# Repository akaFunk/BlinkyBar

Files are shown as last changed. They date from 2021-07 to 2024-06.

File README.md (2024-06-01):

# BlinkyBar
The BlinkyBar is a modular LED light painting device based on the WS2812B programmable RGB LEDs. It features modules with a length of approximately 250mm, which can be attached to a host module of an arbitrary length. The host module holds a Raspberry Pi Zero W, which provides access to the device with a Wifi access point. A website running on the Raspi allows to upload an image. Once the trigger button on the host module is pressed, the image is played back one column after another. Combining this with a long time expose will paint the uploaded image into thin air.

We are currently working on the first release. Images made with an earlier version are shown below. This older version featured only 60 LEDs per meter, while the new one will have 180 LEDs per meter.

## Images
Examples of the old version:
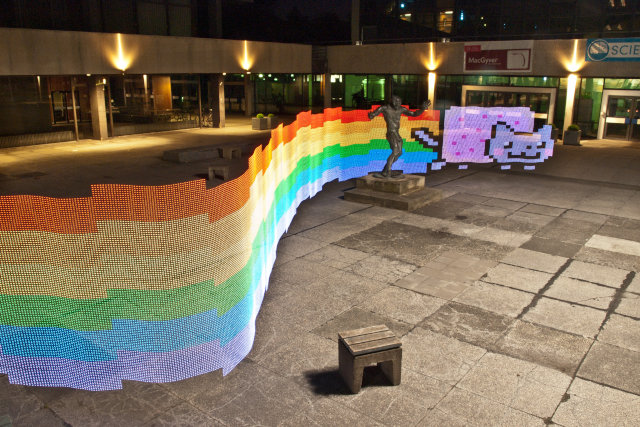
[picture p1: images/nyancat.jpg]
Example Image 1

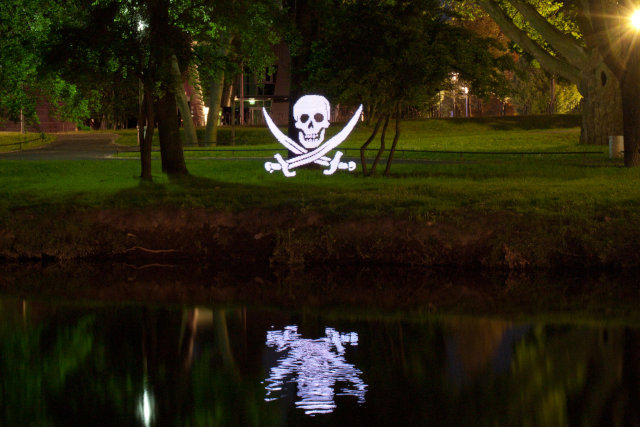
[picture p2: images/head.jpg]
Example Image 2


3D rendering of the current main module:
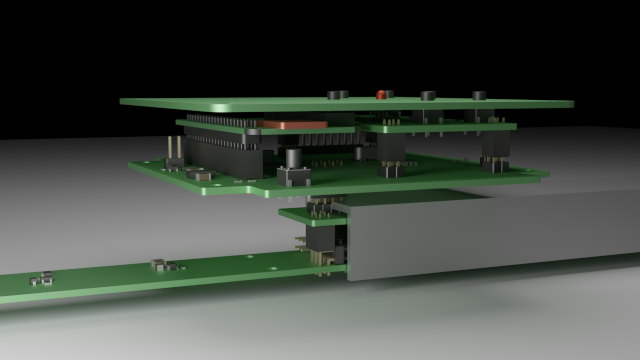
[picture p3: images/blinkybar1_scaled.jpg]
Example Image 1

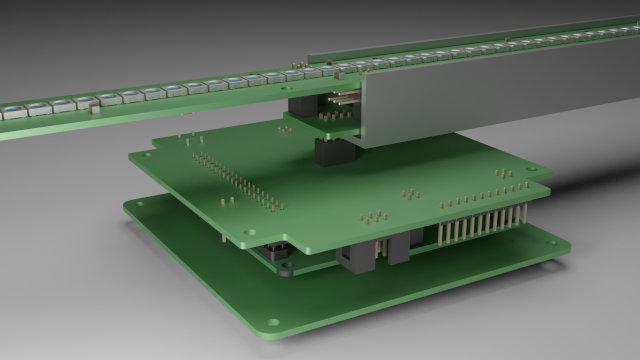
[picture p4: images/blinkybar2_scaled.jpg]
Example Image 1


Images of the first prototype:
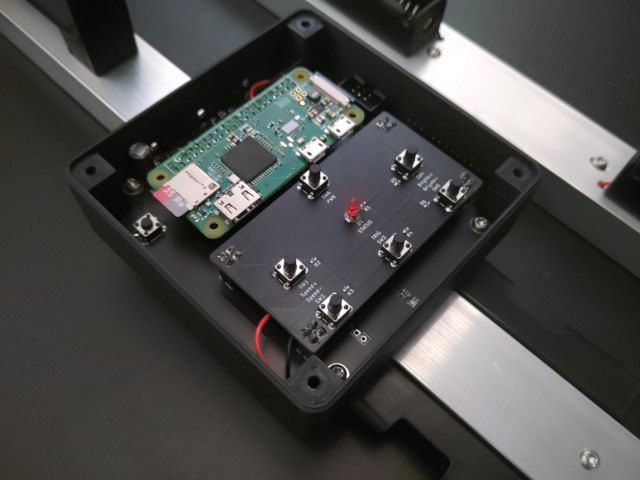
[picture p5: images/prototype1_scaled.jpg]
Example Image 1

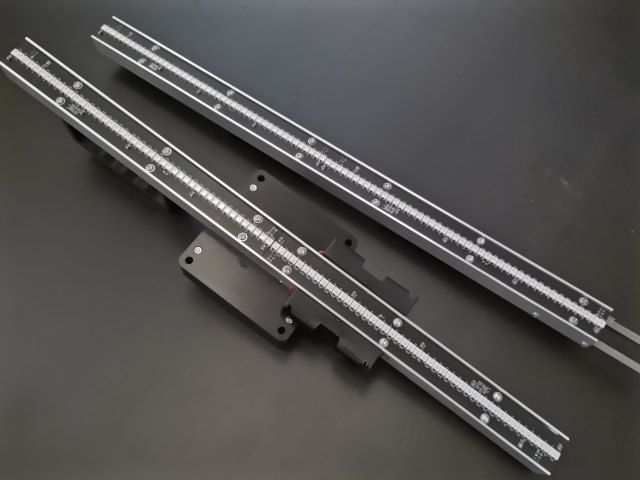
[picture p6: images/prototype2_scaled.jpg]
Example Image 1

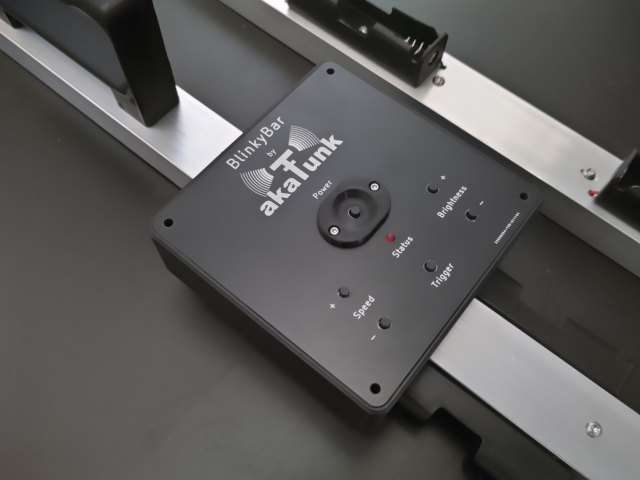
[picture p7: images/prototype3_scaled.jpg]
Example Image 1

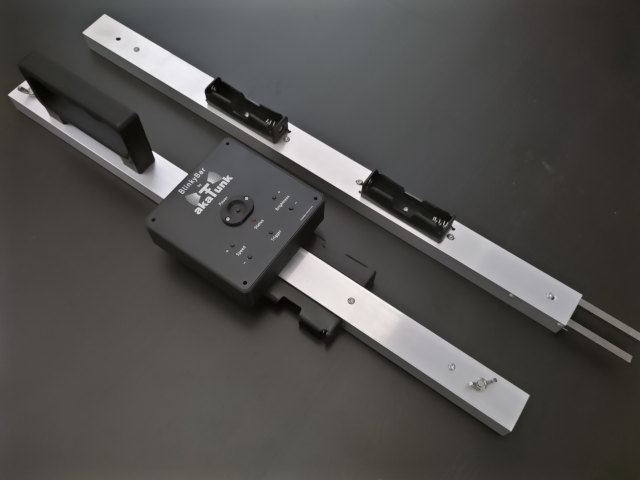
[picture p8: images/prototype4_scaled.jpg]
Example Image 1


## Building BlinkyBar

### Issues to be aware of
BlinkyBar is still in development and there are currently a few issues, which are important to note if you want to build it. They will be addressed in the future:
- The 1117 LDO is not working with the currently populated MLCC output capacitors. Their ESR is too low. You will hear an annoying high pitch tone and have a ~400 mVpp triangle on the output voltage. Either replace the output capacitors with Aluminium Electrolytic types, solder a 0.5 Ohm resistor in series with the capacitors, or use a different LDO (for example BL8071CLBTR33 or AP2114H-3.3TRG1). Currently we have tested only using the Aluminium Electrolytic caps which works fine.
- The modules are not able to power down automatically if the host module powers down. Please make sure to remove the batteries, otherwise they will be empty after some time. However, the battery under-voltage protection should work for both the host and the modules, so your batteries are safe.

### Parts
Additional part required for a BlinkyBar with 4 modules and the main unit, i.e., 10 module PCBs and a length of 2475 mm and 450 LEDs.
For the PCBs you will find lists in CSV format exported from KiCad in each of the PCBs output folder.

| Description | Count | 3D Model |
|---|---|---|
| U-Profile, 30x20x2x495 mm (WxHxTxL), Aluminum | 1 | main_profile |
| U-Profile, 30x20x2x495 mm (WxHxTxL), Aluminum | 4 | module_profile |
| 6x6x100 mm, Steel | 8 | module_bolt |
| 3D-printed stand for the module PCB | 15 | module_stand |
| 3D-printed power button protector | 1 | main_button_protector |
| 3D-printed main case | 1 | main_case |
| 3D-printed handle | 1 | main_handle |
| 18650 Holder | 12 | 18650_holder |
| Plate, 35x25x3 mm, Steel | 4 | module_plate |
| Main PCB holding the Raspberry Pi Zero and the user interface PCB | 1 | main_pcb |
| Main PCB adapter to combine and raise the two connector fro the module pcb within the main module | 1 | main_pcb_adapter |
| Main PCB front panel as the case cover | 1 | main_pcb_front |
| Main PCB user interface holding a few buttons and an LED | 1 | main_pcb_ui |
| Module PCB with the LEDs | 10 | module_pcb |
| M4x12 wing screw (DIN 316) | 4 | |
| M3x5 flat head screw (ISO7380) to hold the case to the profile | 2 | |
| M3x4 countersunk head screw (ISO 14581) to hold the battery holders | 24 | |
| M3 nut (ISO 4032) to hold the battery holders in the main case | 4 | |
| M3x8 flat head screw (ISO7380) to hold the main PCB in the case | 4 | |
| M3 nut (ISO 4032) to hold the main PCB in the case | 4 | |
| M3x20 flat head screw (ISO7380) to hold the front panel PCB to the case | 4 | |
| M3 nut (ISO 4032) to hold the front panel PCB to the case | 4 | |
| M3x12 flat head screw (ISO7380) to hold the stand to the profile | 28 | |
| M3x20 flat head screw (ISO7380) to hold the handle and two of the stands to the profile | 2 | |
| M3 nut (ISO 4032) to hold the stand to the profile | 30 | |
| M3x8 flat head screw (ISO7380) to hold the module PCB to the stand | 60 | |
| M3 nut (ISO 4032) to hold the module PCB to the stand | 60 | |
| M2x5 flat head screw (ISO7380) to hold the power button protector to the front panel PCB | 2 | |
| M2 nut (ISO 4032) to hold the power button protector to the front panel PCB | 2 | |
| M3x8 flat head screw (ISO7380) to hold the steel bolts to the profile | 16 | |

### Replacement parts
Some MPN in the CSV/schematics are just some random ones, for example for pin headers, which fit and were available at the time of design. Those may be replaced with similar types. A (bar far not complete) list of such parts is given below:

| Part | Description |Replacements |
|---|---|---|

# TODO/Further development
- Make everything much simpler, especially the bus topology, mechanical design, and power design
- Use smaller LEDs, for example SK6805-EC15, and increase LED density

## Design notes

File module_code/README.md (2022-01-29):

# Module Microcontroller Code
This folder contains the code for the microcontroller located on each module. This micro will receive the image data which will be used for the module's LEDs, save it into the flash memory and play it back once triggered.

The used microcontroller is an ATmega328p, which is the same as the one on the Arduino Uno. But we do not support the Arduino bootloader or using the Arduino IDE. This is a larger project and for that one should use proper tools.

## Building & Flashing
You need the avr-gcc and avr-binutils packages for building. Flashing requires avrdude and an external ISP prommer like the AVR ISP mkII, Atmel ICE, or similar.

To build the sources (there is also a pre-compiled hex file) type
```sh
$ make
```

After that you should modify the Makefile to fit your prommer. By default an Atmel ICE is expected, connected to the ISP header. See
```sh
$ avrdude -c help
```
for a list of supported prommers. After doing that flash each module with:
```sh
$ make flash
```
You may also want to burn the fuses:
```sh
$ make fuses
```
If you get some error message telling you that he was not able to access your prommer, your user probably doesn't have the right permission to access it. Use your favorite internet search engine to solve this problem, the keywords you are looking for are the name of your prommer, avrdude and udev (you need to add udev rules for it). If you are lazy, just run the install command with root privilegs.

## Bus System and Packets
A small recap of the hardware structure, for a detailed explanation of the hardware take a look at the folder ../Module_PCB.

The modules are daisy-chained through their UART. The TX of the host goes to the RX of the first module, the first module's TX goes to the second module's RX and so on. This is the downstream path.

There is also an upstream path. Each module can (software-controlled) bridge it's TX to the return path. The last module is the one which actually has to do this to get a closed daisy-chain.

Besides the daisy-chain there is the additional TRIGI/TRIGO signal. This signal comes from the microcontroller on the host. A rising edge on this signal signals the trigger for the output of the next column of the image.

The daisy-chained connection is used to transmit packets between the host and the modules. The packet's header contains information about the source and destination address, the type of the packet (i.e., a command), as well as the length of the data, and a few other things. The data follows the header and may have a length of up to 256 bytes and may also be of zero length.

If a packet's desination address is either the broadcast address or does not match the modules address, it is forwarded to the next module.

The big question is: How does a module determine its address? We decided against a hardware coding, as the modules would not be as modular - obviously. The host first sends a message to the broadcast address, telling every module to disable its uplink path and just transmit the packets to the next modules. In this configuration the host will not get any packets form the last module, as it will only forward them to the next module, which does not exist. This "return reset" message also causes all modules to set their address to 0. Next, the host will transmit a command to this address, containing a new unique address. The first module receives this message, sets its new address, enables the return path, acknowledges the reception, and disables the return path. This process is repeated until the host does not receive any answer. The last module that did answer will then get an extra message, telling it to enable its return path.

Here is the structure of the packet:
```c
typedef struct
{
    uint8_t magic;
    uint8_t type;
    uint8_t src;
    uint8_t dst;
    uint16_t len;
    uint8_t data[MESSAGE_MAX_DATA_SIZE];
} message_t;

```
with the following parameters:
- **magic** is a magic byte of value 0xab, which is always the first byte of a message. It is used to identify the start of a message in case of a loss of synchronization. Eventually a module will re-synchronize after a few packets.
- **type** is the type or command of the message, see below.
- **src** is the the source address. The host is 0xfe and 0xff is the broadcast address.
- **dst** is the destination address.
- **len** is the length of the data field as little endian.
- **data** is the data, which may have any length between 0 and 256.

The following message types are known:
- **MESSAGE_TYPE_RET_RST**: Reset the modules address, disable return path (RETO, ~RET_EN), always a broadcast message, len=0
- **MESSAGE_TYPE_ADDR**: New address for the module, len=1 (new address). The module will set the new address, enable the return path, send an ack message, and disable return path.
- **MESSAGE_TYPE_RET_SET**: Enable the module's return path (RETO, ~RET_EN), len=0.
- **MESSAGE_TYPE_PING**: Ping message, response with an ACK.
- **MESSAGE_TYPE_STAT**: Display a status value with the LEDs, len=1 (status vlaue).
- **MESSAGE_TYPE_DEL**: Delete the module's flash, len=0. ACK is returned when flash is deleted. Note that the module will not forward other messages while deleting the flash. It is therefore advised to send this message either as a broadcast or to the last module in the chain at first.
- **MESSAGE_TYPE_DATA**: Next data block for the module, len=1..256. The flash block size is 256 bytes and one column has 135 bytes per module.
- **MESSAGE_TYPE_PREP**: All data transmitted to modules, signal for the modules to prepare for trigger, len=0. The module will load the first set of data into the RAM.
- **MESSAGE_TYPE_TRIG**: Trigger a column - just for debug purposes, normal operation is though TRIGI signal interrupt.
- **MESSAGE_TYPE_DONE**: Playback is done, normal operation can continue.
- **MESSAGE_TYPE_ACK**: ACK last message (also used as pong), len=0.
- **MESSAGE_TYPE_NACK**: NACK last message, len=0.

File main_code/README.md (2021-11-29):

# Main PCB AVR code
This folder contains the code for the AVR on the main PCB. The purpose of this controller is battery monitoring, power management, and generation of the trigger signal for the modules.

Once the controller turns on by pushing the button connected to the `MASTER_ON` signal, it is responsible to set `PWR_EN` high to keep the power supply turned on. If the battery voltage is too low, the AVR will turn off the power supply by driving the `PWR_EN` line low. This will also turn off the power of the AVR itself. Before that it will notify the Pi, so the Pi can shut down the modules as they will not be needed if the main module has no power.

The AVR talks to the Raspberry Pi using an SPI. On the Pi side the SPI1 is used in master mode, which needs to be activated using an additional overlay. See the readme file in `buildroot_external` folder for details on that. The AVR uses its only internal hardware SPI, which is shared with the `ISP` interface for promming the AVR. The two 330 Ohm resistors `R7` and `R8` make sure that there are no collisions while debugging and the `ISP` interface is the primary one. The AVR runs at 8 MHz. 16 MHz is not possible, as the supply voltage is only 3.3V.

The Pi will set the period and on time of the trigger signal, how many colums there are and it will start/stop the trigger signal.

## SPI protocoll
The SPI clock should be fairly low, to make sure that the AVR can keep up. Don't know the exact value, 10 kHz works.

The protocoll is a single packet of 5 bytes in both directions. These 5 bytes have to be encapsulated in a single chip-select sequence. The packet from the Pi to the AVR contains the following data, all values are little endian:

| Bytes | Meaning |
|---|---|
| 1 | Command flags: <br> bit 0: start trigger<br>bit 1: stop trigger <br> bit 2: infinite repeat <br> If nothing is set, the Pi only wants to read the voltage/timer_counter and no action is carried out and the local state is not altered. |
| 2 | Period of the trigger signal, given in µs |
| 2 | On-time of the trigger signal, given in µs |
| 2 | Trigger count, number of negative pulses on the trigger line |

And the answer, which is returned in each request contains the following information:

| Bytes | Meaning |
|---|---|
| 1 | Magic byte, always 0x31 |
| 2 | Battery voltage, given in mV |
| 2 | Current timer counter value of the current progress, which counts from 0 to the period value minus 1 |
| 1 | Shutdown request, 1 if the power button was pressed or the battery voltage is too low, otherwise 0 |
| 1 | Magic byte, always 0x41 |

TODO: Add a automatic shutdown if we have not heard from the Pi in a while. This would also be helpfull for the modules.

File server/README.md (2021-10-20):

# BlinkyBar Server

The server is small Python script running on the main module's Raspberry PI Zero W. The Pi provides a Wifi access point. Once connected, the server is reachable under http://192.168.138.1. The server provides the necesarry website and API to control the BlinkyBar. This includes uploading images, setting the speed, brightness, trigger delay, and a few other things. It also allows to trigger the BlinkyBar, additionally to the hardware button on the BlinkyBar itself.

## API

The server is written in Python 3 and based on [cherrypy](cherrypy.org), which provides a simple webserver and integrates easily into python. There are three different endpoints for the API:

### settings

Settings can take several parameters:

-   **speed** is a floating point value between 0.1 and 10, given in meters per second. It defines the column playback speed of the image. The default value is 2.0.
-   **brightness** is the brightness of the image as a floating point value between 0 and 1. Settings this value will trigger an upload of the image to the modules. The default value is 1.
-   **color_temperature** is the temperature of the surrounding light sources. The image is converted to reflect this color temperature. The default value, which makes (almost) no changes to the image is 6500 K. The valid range is between 1000 and 10000 K.
-   **trigger_delay** sets the delay between pressing the trigger button and starting the playback of the image. The value is given in seconds and any positive floating points value is allowed. The default value is 0.
-   **mirror** mirrors the image. A change will trigger an image upload.
-   **allow_scaling** defines if the BlinkyBar is allowed to scale the image or not. This allows to prepare pixel-precise images. Note that if the image height is exactly the same as the number of available pixels, the BlinkyBar will not scale the image as well. If scaling is not allowed and the image is smaller than the current BlinkyBar configuration, only the upper pixels will be used. If no scaling is allowed and the image is larger, the image will be cut at the bottom. Accepted values are true or false. A change of this value might trigger an image upload, if the result will be different. The default value is true.
-   **repeat** defines, if the image shall be repeated endlessly.
-   **pixel_mode** defines, if the playback should display pixels instead of hoizontal lines. If turned on, the modules will turn the LEDs on and off for each column with a durty cycle of 50 %, creating pixels in stead of horzontal lines.

All parameters are optional. A query looks, for example, like this:

http://192.168.138.1/settings?speed=1.0&allow_scaling=true

All queries will return a JSON string with the following structure:

```json
{
    "success": true,
    "error_msg": "",
    "brightness": 0.5,
    "speed": 0.5,
    "color_temperature": 6000,
    "trigger_delay": 1.0,
    "mirror": false,
    "allow_scaling": true,
    "repeat": false,
    "pixel_mode": true,
    "image_hash": "01ba4719c80b6fe911b091a7c05124b64eeece964e09c058ef8f9805daca546b",
    "progress_status": "noimage",
    "prograss_value": 0.0,
    "progress_msg": "",
    "system_error_msg": ""
}
```

If the "success" variable is false it indicates an error in the query. In that case the "error_msg" holds an error message.

Additionally the structure holds a few variables, indicating the state of the system:

-   **image_hash** contains the hash of the current scaled image, which can be used by the frontend to figure out if the image has changed since the last request. If that is the case, the frontend can ask for the new image.

-   **progress_status** may be any of "noimage", "processing", "ready", or "playing". "noimage" means that no image is available to be triggered, "processing" means that an uploaded image is currently being processed, "ready" means that the uploaded image is ready to be triggered, and "playing" means that the image is currently beeing played back. In the last case, a trigger will stop the playback.

-   **prograss_value** is a float value between 0 and 1. It can be used to display a loading bar while the an image is beeing processed or played. It is only valid if "progress_status" is either "processing" or "playing".

-   **progress_msg** contains a more detailed message about what is currently happening, especially during the image processing. It is only valid if "progress_status" is either "processing" or "playing".

-   **system_error_msg** may contain a system critical error message. If this string is not empty, the BlinkyBar will not function as expected and the message should be shown to the user.

### set_image

Upload an image to the BlinkyBar. The image has to be attached in the POST as a multipart/form-data object in the variable image_obj. A new image will trigger an image upload to the modules.

The endpoint is: http://192.168.138.1/set_image + POST data

### get_image

Returns the currently stored image. The server internally converts the image to a PNG file on upload and this is what you will get here.

Here is an example: http://192.168.138.1/get_image

### get_image_scaled

Returns the scaled version of the image, which is currently used for the LEDs. The image is of type PNG.

Here is an example: http://192.168.138.1/get_image_scaled

### Trigger

Triggers the image playback. If the playback is already running, it stops it. Can only be called if "progress_status" is "ready" or "playing".

## Website

The website is delivered by the server to the webbrowser and provides the GUI for the BlinkyBar. The application is based on [Vue.js](https://vuejs.org/), version 3.

TODO: A detailed description to follow, once implemented ;)

TODO: Screenshots

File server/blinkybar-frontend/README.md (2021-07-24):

# ledleiste-frontend

## Project setup
```
npm install
```

### Compiles and hot-reloads for development
```
npm run serve
```

### Compiles and minifies for production
```
npm run build
```

### Lints and fixes files
```
npm run lint
```

### Customize configuration
See [Configuration Reference](https://cli.vuejs.org/config/).

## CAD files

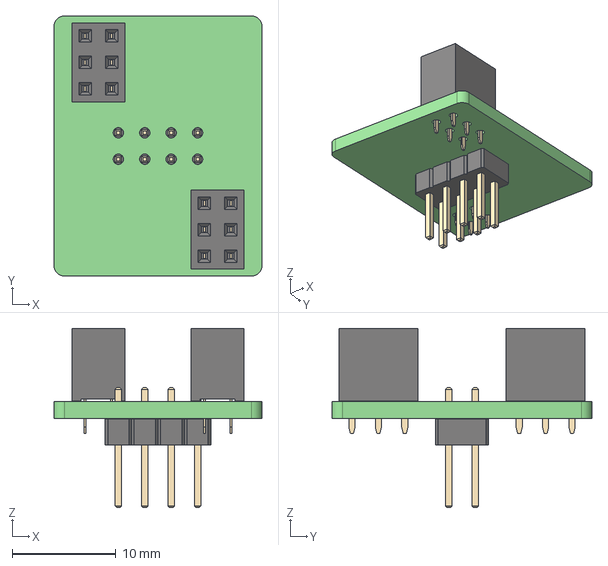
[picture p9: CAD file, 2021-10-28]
main_pcb_adapter/main_pcb_adapter.step
20.0 x 25.0 x 17.2 mm

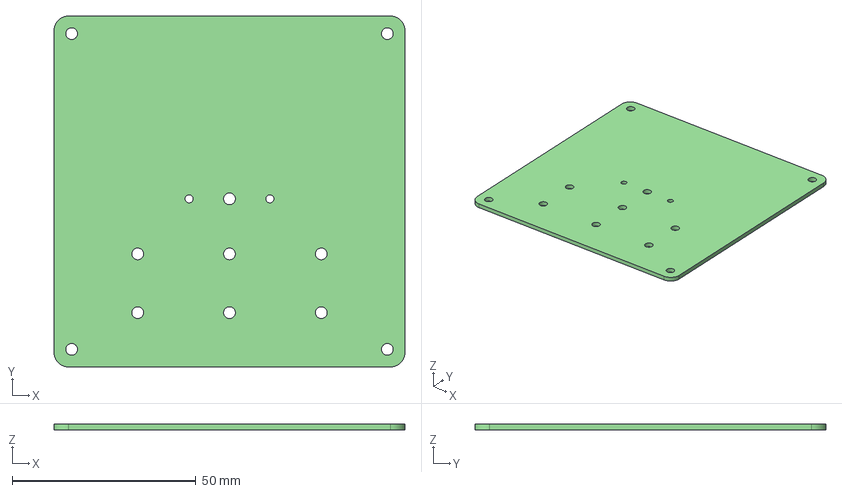
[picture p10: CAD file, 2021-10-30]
main_pcb_front/main_pcb_front.step
95.6 x 95.6 x 1.60 mm

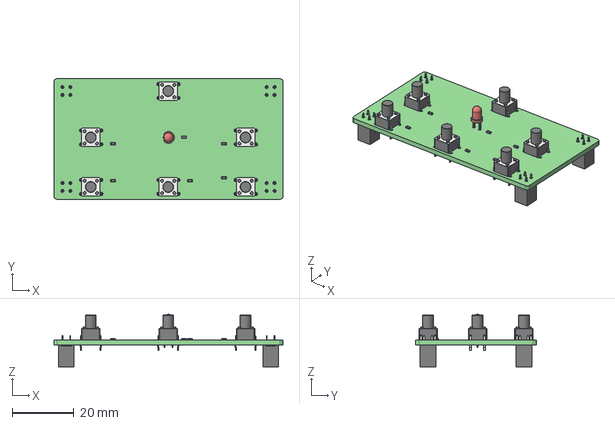
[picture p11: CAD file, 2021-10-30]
main_pcb_ui/output/main_pcb_ui.step
74.0 x 39.0 x 17.0 mm

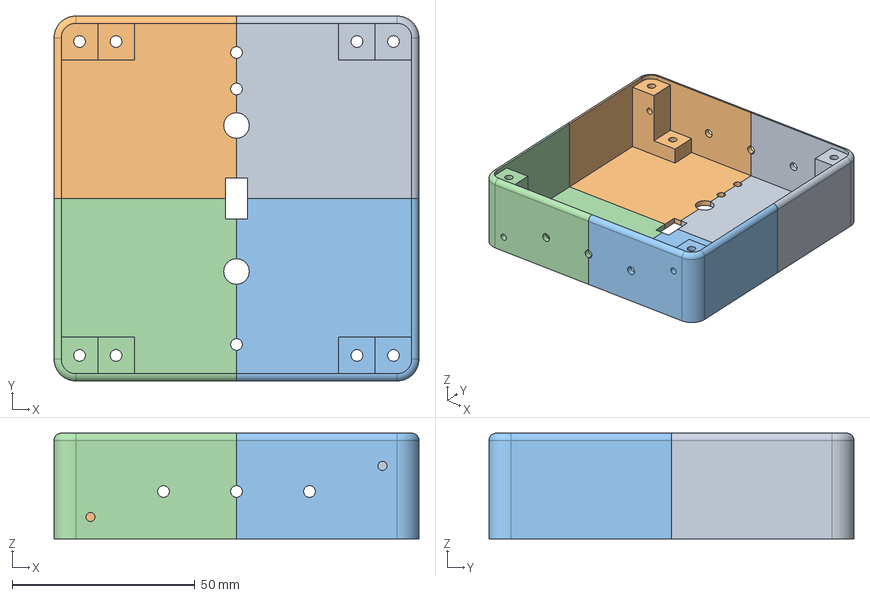
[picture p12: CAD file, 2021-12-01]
mechanics/main_case.step
100.0 x 100.0 x 29.0 mm

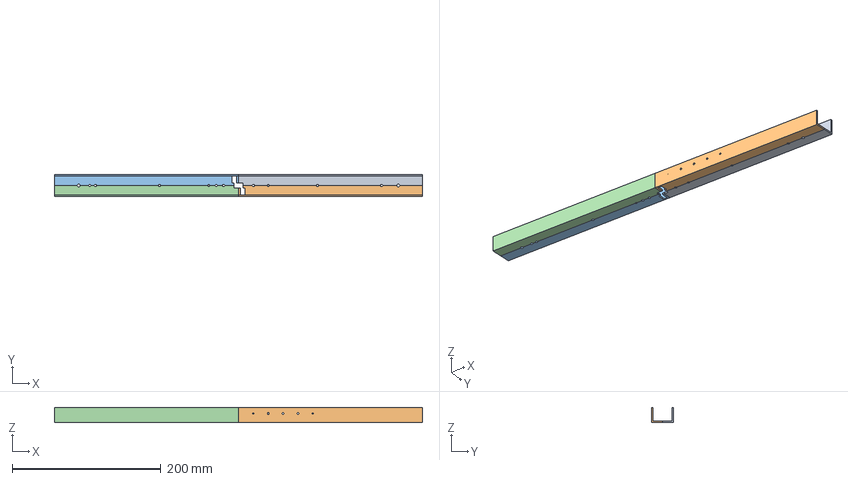
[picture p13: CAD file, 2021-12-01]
mechanics/main_profile.step
495.0 x 30.0 x 20.0 mm

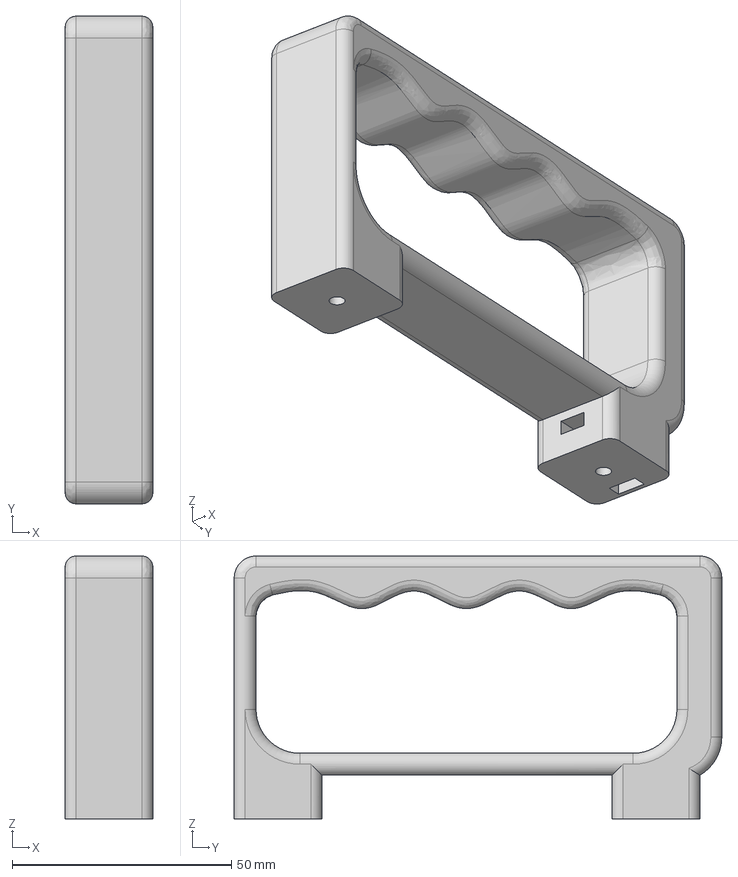
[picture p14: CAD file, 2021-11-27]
mechanics/main_handle.step
20.0 x 111.2 x 60.0 mm

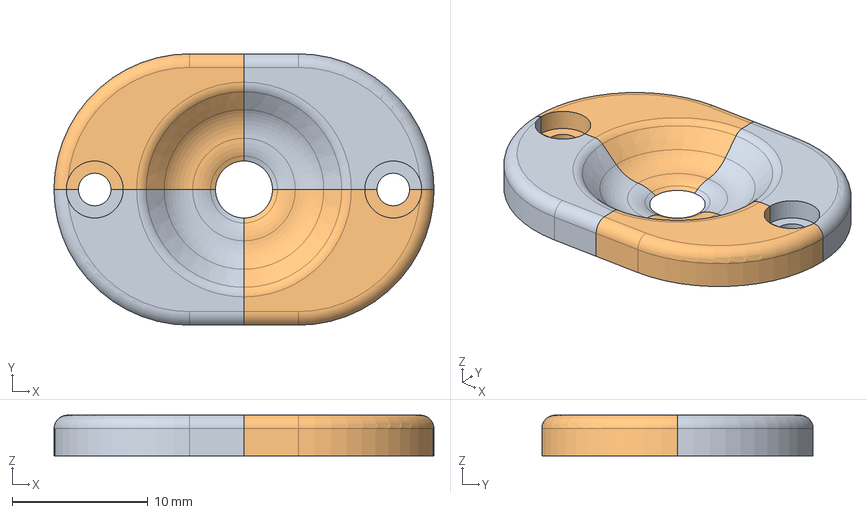
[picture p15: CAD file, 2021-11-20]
mechanics/main_button_protector.step
28.0 x 20.0 x 3.00 mm

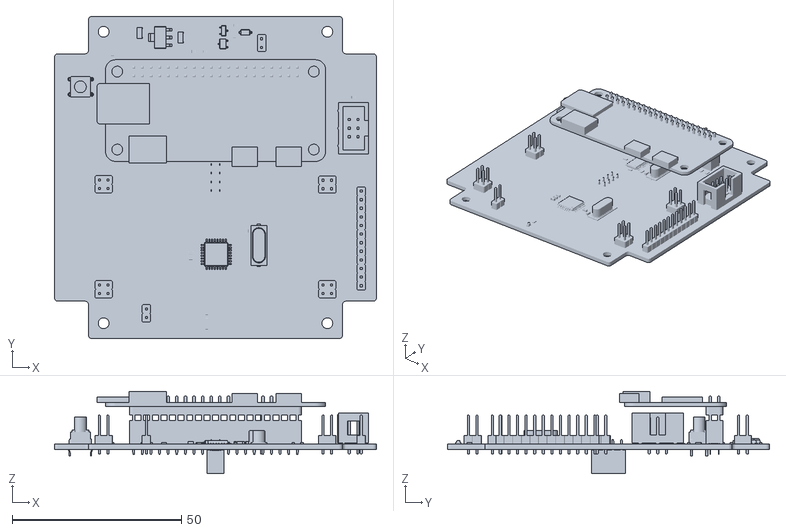
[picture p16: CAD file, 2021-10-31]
mechanics/main_pcb.stl
95.0 x 95.0 x 24.2

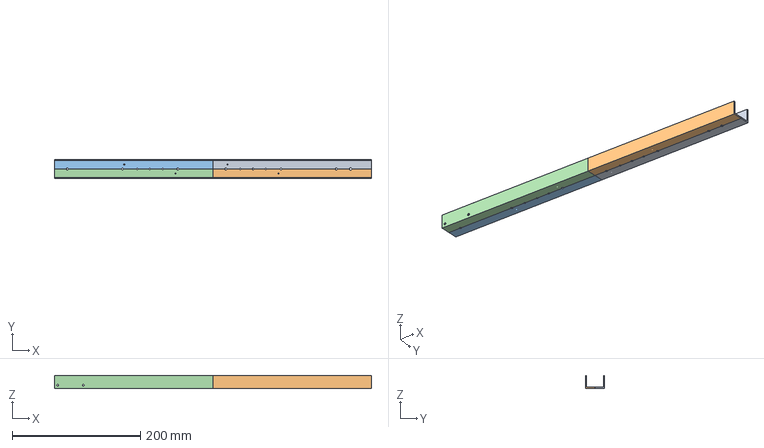
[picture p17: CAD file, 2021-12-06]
mechanics/module_profile.step
495.0 x 30.0 x 20.0 mm

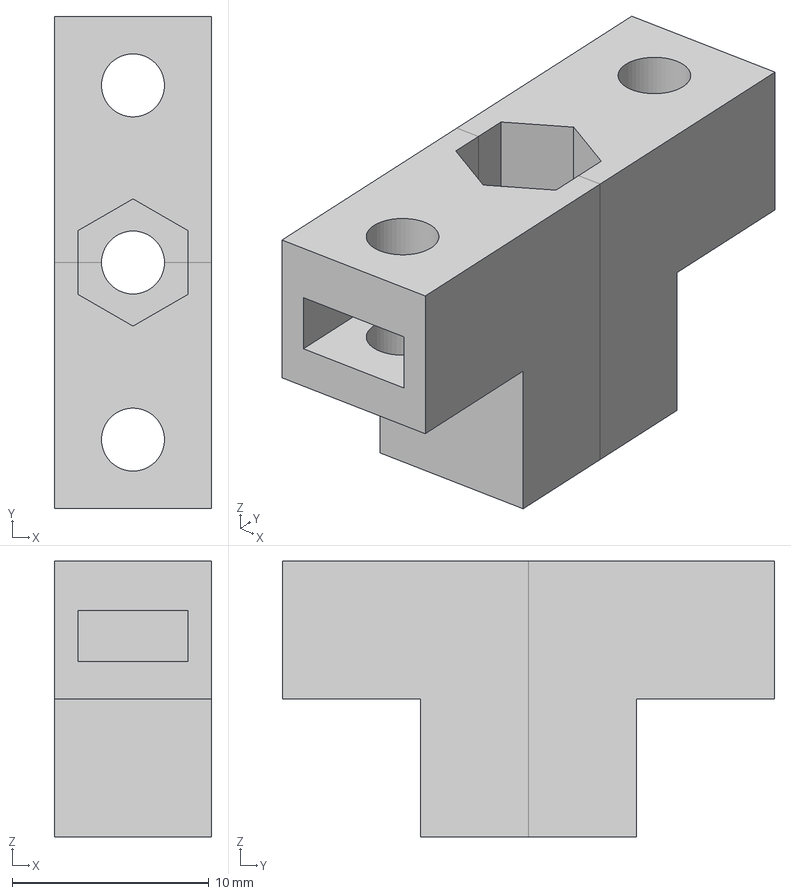
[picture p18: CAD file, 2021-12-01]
mechanics/module_stand.step
8.00 x 25.0 x 14.0 mm

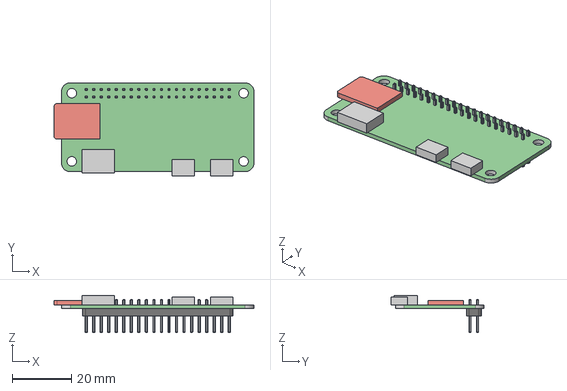
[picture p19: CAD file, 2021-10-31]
mechanics/PiZero.step
67.5 x 31.5 x 12.6 mm

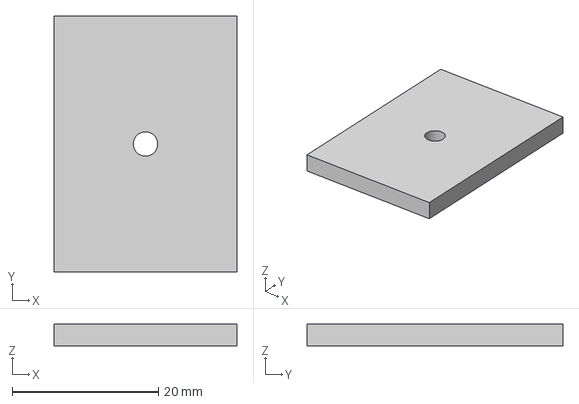
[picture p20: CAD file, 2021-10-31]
mechanics/module_plate.step
25.0 x 35.0 x 3.00 mm

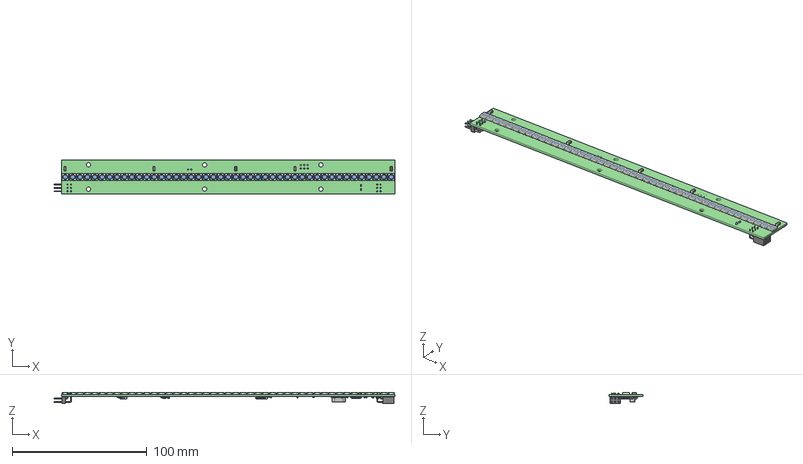
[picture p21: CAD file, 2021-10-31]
mechanics/module_pcb.step
253.1 x 25.0 x 8.38 mm

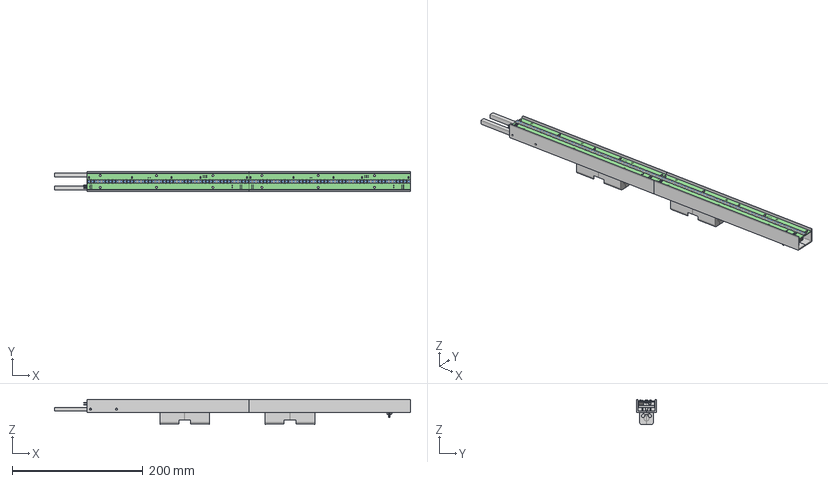
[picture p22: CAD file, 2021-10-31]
mechanics/module.step
545.0 x 30.0 x 38.5 mm
module_stand x 6
module_profile
module_bolt x 2
92595A200_Iron Wing-Head Thumb Screw
module_plate
18620_holder x 2

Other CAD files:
main_pcb_adapter/output/main_pcb_adapter.step
mechanics/main_pcb_ui.step
mechanics/main_pcb_adapter.step
mechanics/main_pcb_front.step
mechanics/18620_holder v3.f3d
mechanics/18620_holder v3.step
mechanics/18620_holder v3.stl
mechanics/PiZero.f3d
mechanics/PiZero.stl
mechanics/main.f3z
mechanics/main_button_protector.f3d
mechanics/main_button_protector.stl
mechanics/main_case.f3d
mechanics/main_case.stl
mechanics/main_handle.f3d
mechanics/main_handle.stl
mechanics/main_pcb.f3d
mechanics/main_pcb_adapter.f3d
mechanics/main_pcb_adapter.stl
mechanics/main_pcb_front.f3d
mechanics/main_pcb_front.stl
mechanics/main_pcb_ui.f3d
mechanics/main_pcb_ui.stl
mechanics/main_profile.f3d
mechanics/main_profile.stl
mechanics/module.f3z
mechanics/module_bolt.f3d
mechanics/module_bolt.step
mechanics/module_bolt.stl
mechanics/module_pcb.f3d
mechanics/module_plate.f3d
mechanics/module_plate.stl
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

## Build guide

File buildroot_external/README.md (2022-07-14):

# Buildroot config
You need a Linux on the Raspberry Pi Zero with some custom configuration (including device-tree stuff). This folder includes the files required to make a custom buildroot build. This custom embedded Linux has a few advantages:
- The image only includes what is really needed. This will decrease the size of the image substantially (currently we need less than 100 MB) and it also improves the boot time (currently we need ~5 seconds).
- The image contains multiple partitions. The boot and system partition are mounted read only (including noatime). The data partition contains the current configuration. It is mounted rw only when required. This reduces wear of the SD card and the risk of a damaged it when the Pi is turned off without a proper shutdown.
- We need a custom device tree to enable the SPI to UART converter, which can be easily integrated into the buildroot system.
Nevertheless, it is possible to use the standard RaspiOS with the mentioned downsides. A tutorial how to set it up is given below.

## How to build

```bash
git clone git://git.busybox.net/buildroot
cd buildroot
git checkout 2021.02
make BR2_EXTERNAL=../path/to/repo/buildroot_external/ BlinkyBar_defconfig
make
```

Das SD-Karten-Image liegt im Buildrootordner unter output/images/sdcard.img.

## Using Raspberry Pi OS
Here is a step-by-step guide on how to set up a RaspiOS for the BlinkyBar. It is also helpful if you want to learn what we have done to the buildroot to get everything up and running.

### Connecting to the Pi
The system is a so-called headless-system. You don't have (need) a monitor or keyboard. To get access to the Pi there are several options. The easiest one is to use Wifi and SSH. We will first tell the Pi to connect to your local Wifi network and enable SSH. Later, we will reconfigure the Pi to provide an access point. This has to be done later, as we will need to download some stuff.

Flash the Raspberry Pi OS image to an SD card. After that open the boot partition and create a file called `ssh`, which will tell the Pi to enable the ssh server upon first boot. Then create a second file called `wpa_supplicant.conf` with the following content:
```text
country=US
ctrl_interface=DIR=/var/run/wpa_supplicant GROUP=netdev
update_config=1

network={
    ssid="SSID"
    psk="PASSWORD"
}
```
Replace `SSID` with your network name, keep the quotes. Also set the password. You may also want to change the country, which will influence what frequencies the Pi is allowed to use due to different regulatory rules in different countries.

Plug the SD card into the Pi and power it on by pressing the power button for at least 2 seconds. Now open the configuration site of your local Wifi router and find out the IP address of the Pi, connect to it using ssh:
```sh
$ ssh pi@IPADDRESS
```
The default password is `raspberry`.

### Device tree configuration
We need a custom device tree configuration to enable support for SPI1 and the SC16IS752 SPI to dual-UART converter. Add the following lines to `/boot/config.txt` at the very bottom:
```text
dtoverlay=spi1-1cs
dtoverlay=sc16is752-spi0,int_pin=24,xtal=16000000
```
The first line enables SPI1 with one chip-select (GPIO18). SPI1.0 is used as the interface to the AVR on the main PCB. The Pi will send commands to the AVR controlling the trigger signal, including its speed and when to turn on/off. The second line enables the SC16IS752 driver on SPI0 with GPIO24 as the interrupt pin and an external crystal of 16 MHz, which will allow the baud rates 500k and 1M.

After a reboot, make sure you have the SPI1 interface at `/dev/spidev1.0` and the two serial interfaces at `/dev/ttySC0` and `/dev/ttySC1`.

### Serial terminal
As the Wifi will be used for the access point, it may be handy to use a serial terminal for initial communication. To enable the serial terminal, add the line
```
enable_uart=1
```
to `/boot/config.txt`. Also make sure you have the following parameters in `/boot/cmdline.txt`:
```
console=serial0,115200 console=tty1
```
Then connect a USB to serial converter (like FTDI FT232R) to the main module. The RX/TX signals are on the debug header and labeled `PI_TXD` and `PI_RXD`. Make sure to connect RX to TX and vice versa. The names on the BlinkyBar PCB refer to the Pi side.

Then run a serial terminal software like HyperTerminal (Windows) or minicom (Linux) with 115200 baud:
```
minicom -D /dev/ttyUSB2 -b 115200
```

### Dependencies
You need to install a few things before you can start the BlinkyBar main application:
```sh
$ sudo apt install python3-pip libopenjp2-7V python3-numpy python3-rpi.gpio
$ pip3 install cherrypy pillow ujson pyserial
```
Make sure the install the stuff using pip3 with the user which will also run the blinkybar.py server.

Note: numpy is not installed through pip, as we experienced an issue with libcblas.so.3. Raspberry Pi OS puts the symbols into libblas.so and numpy needs to be linked against this library, which is not the case for the current PyPi version.

### BlinkyBar Server
TODO

### Autostart
TODO

### Wifi access point
The Pi will generate a Wifi access point. You connect to it and open the website provided by the BlinkyBar server.

TODO

### Read-Only mode
You can put the Raspberry Pi in a secure read-only mode after you configured everything. To do that run
```sh
$ sudo raspi-config
```
Navigate to `Performance Options` and `Overlay File System`. Enable the overlay file system and make the boot partition write-protected. This will prevent any write to the SD card, making the system much more reliable. But note: Although it is possible to changes files in the filesystem (changes will be stored in the RAM overlay), after a reboot everything is back to the point when you enabled it overlay. So the BlinkyBar will forget its last image and any configuration changes.

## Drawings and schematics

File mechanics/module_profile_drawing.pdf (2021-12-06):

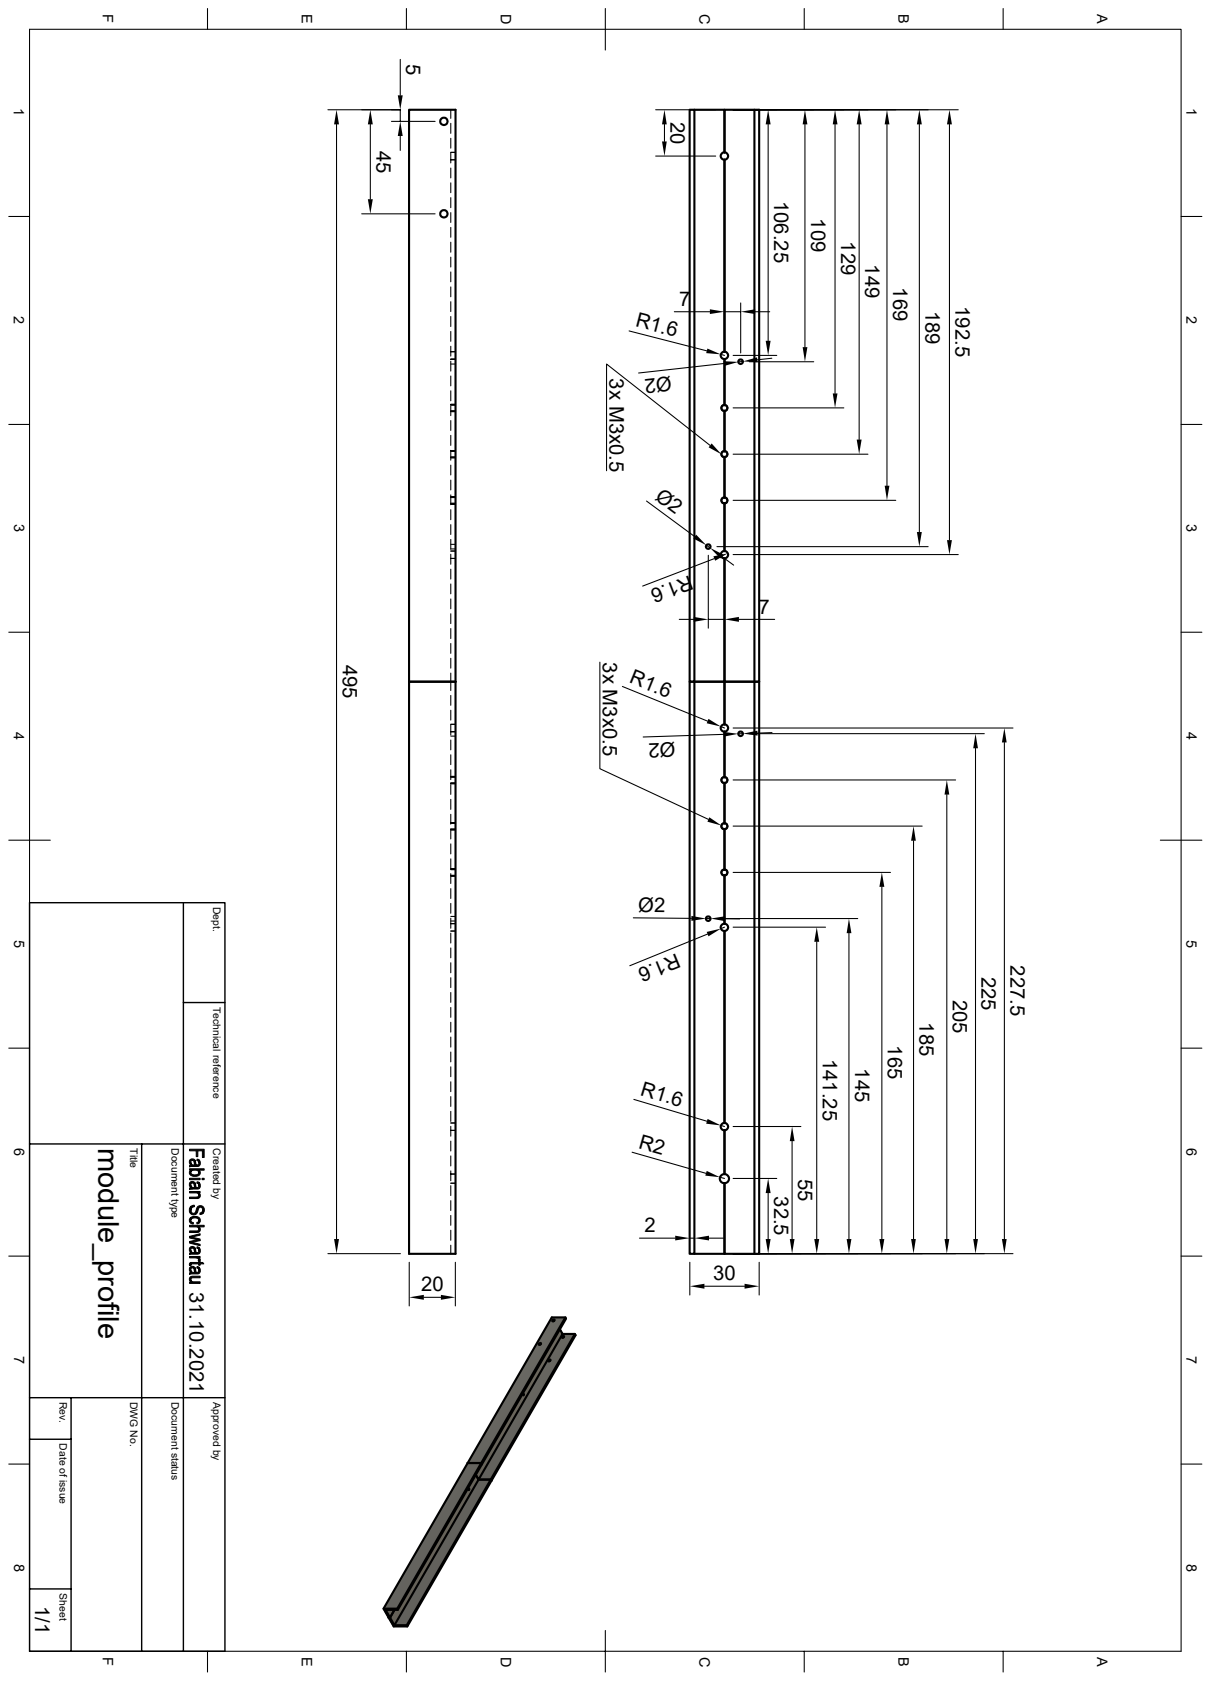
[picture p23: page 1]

1 A 2 3 4 5 6 7 8 1 2 3 4 5 6 7 8 FEDCB FEDCBA Dept. Technical reference Created by Approved by Title DWG No. Document type Document status Rev. Date of issue Sheet 31.10.2021 1/1 module_profile 495 5 45 20 106.25 109129149169189 192.5 7 7Ø2 R1.6 3x M3x0.5 Ø2 R1.6 32.5 55 141.25 145 165 185 205 225 227.5

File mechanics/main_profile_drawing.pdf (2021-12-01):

20 | 30 2⁴⁷.5 | R2R1.6 R1.6 R1.6 R1.6R1.6 M3 M3x0.5 6H R1.6 R1.6R2 Ø2 Ø2 M3 M3 M3

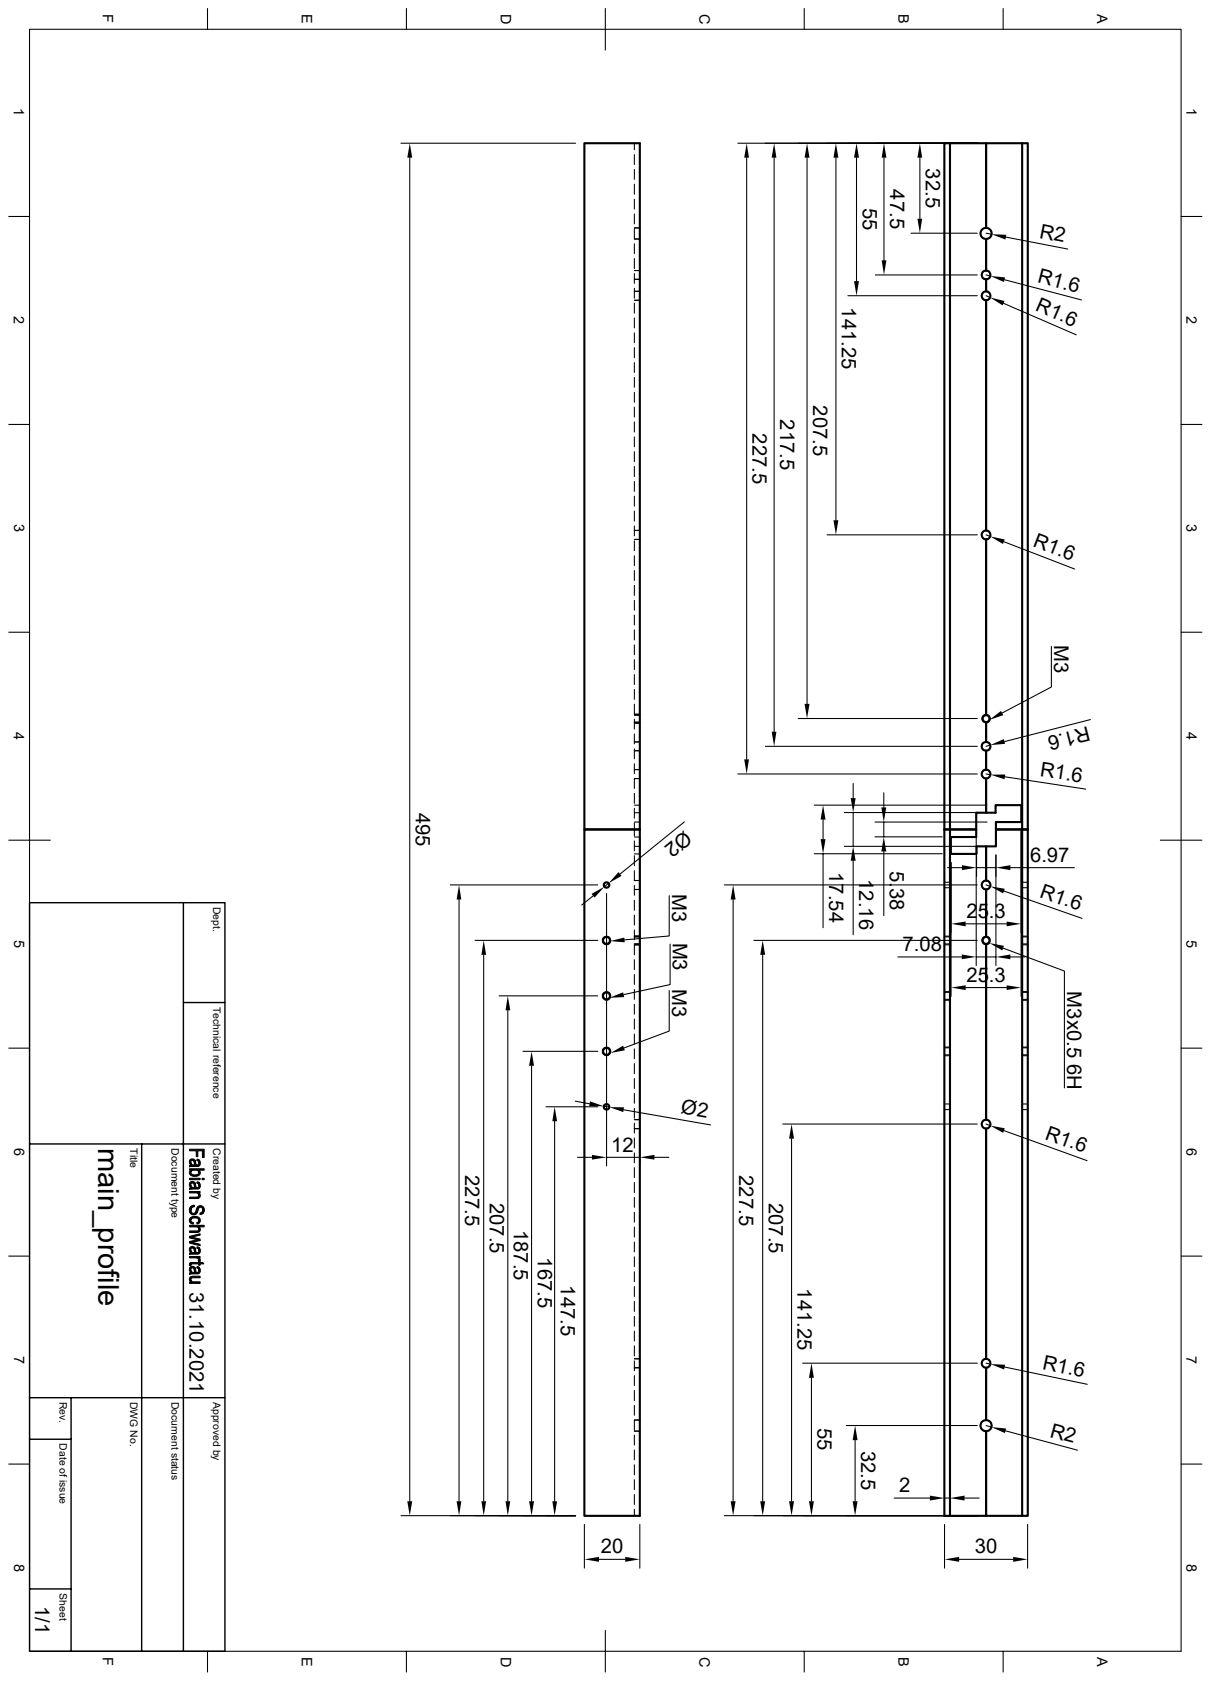
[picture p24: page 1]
25.3 ²¹⁷.5

1 A 2 3 4 5 6 7 8 1 2 3 4 5 6 7 8 FEDCB FEDCBA Dept. Technical reference Created by Approved by Title DWG No. Document type Document status Rev. Date of issue Sheet 31.10.2021 1/1 main_profile 32.555 141.25 207.5227.5 495

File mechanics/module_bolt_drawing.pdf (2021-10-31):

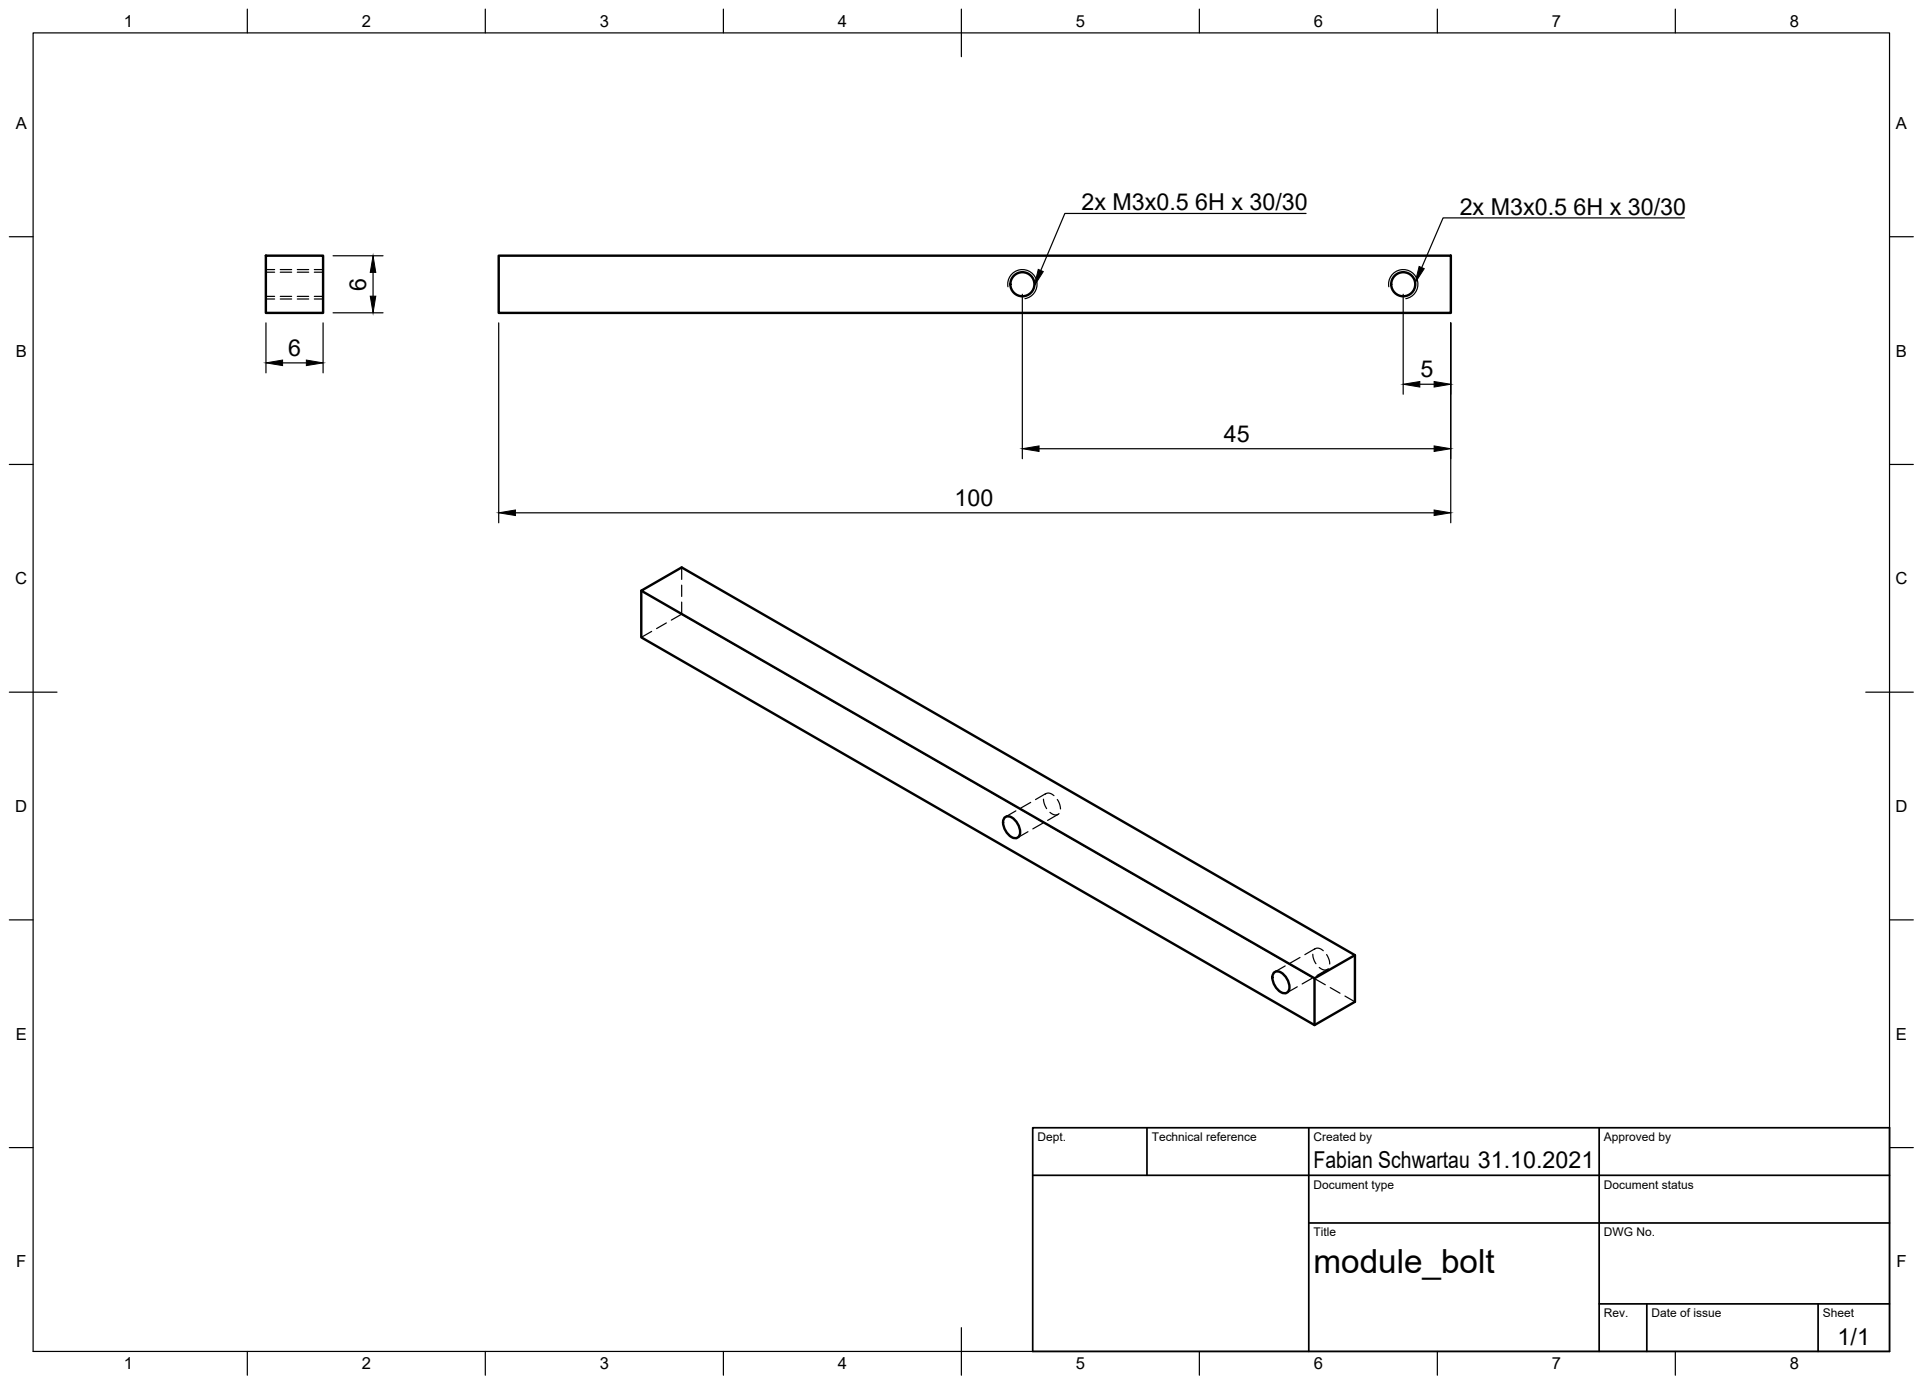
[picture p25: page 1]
Title; DWG No.; Rev.; Date of issue; Sheet

Dept. | Technical reference | Created by Fabian Schwartau 31.10.2021 | Approved by

Document type | Document status

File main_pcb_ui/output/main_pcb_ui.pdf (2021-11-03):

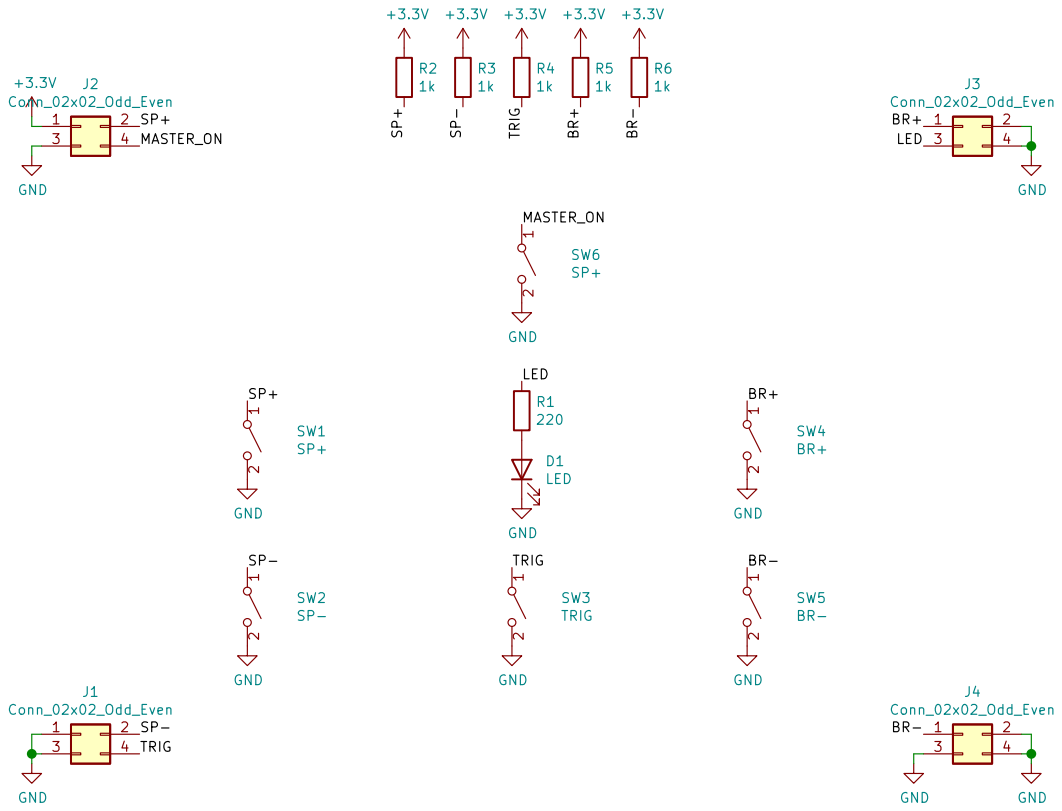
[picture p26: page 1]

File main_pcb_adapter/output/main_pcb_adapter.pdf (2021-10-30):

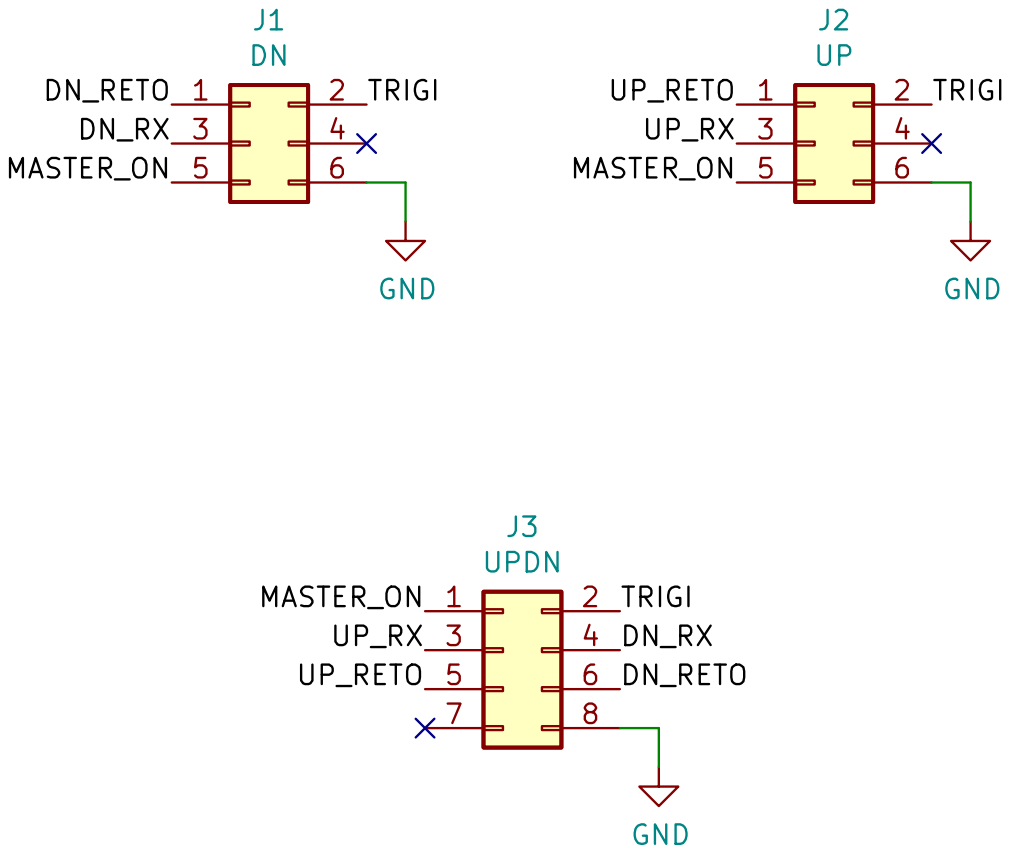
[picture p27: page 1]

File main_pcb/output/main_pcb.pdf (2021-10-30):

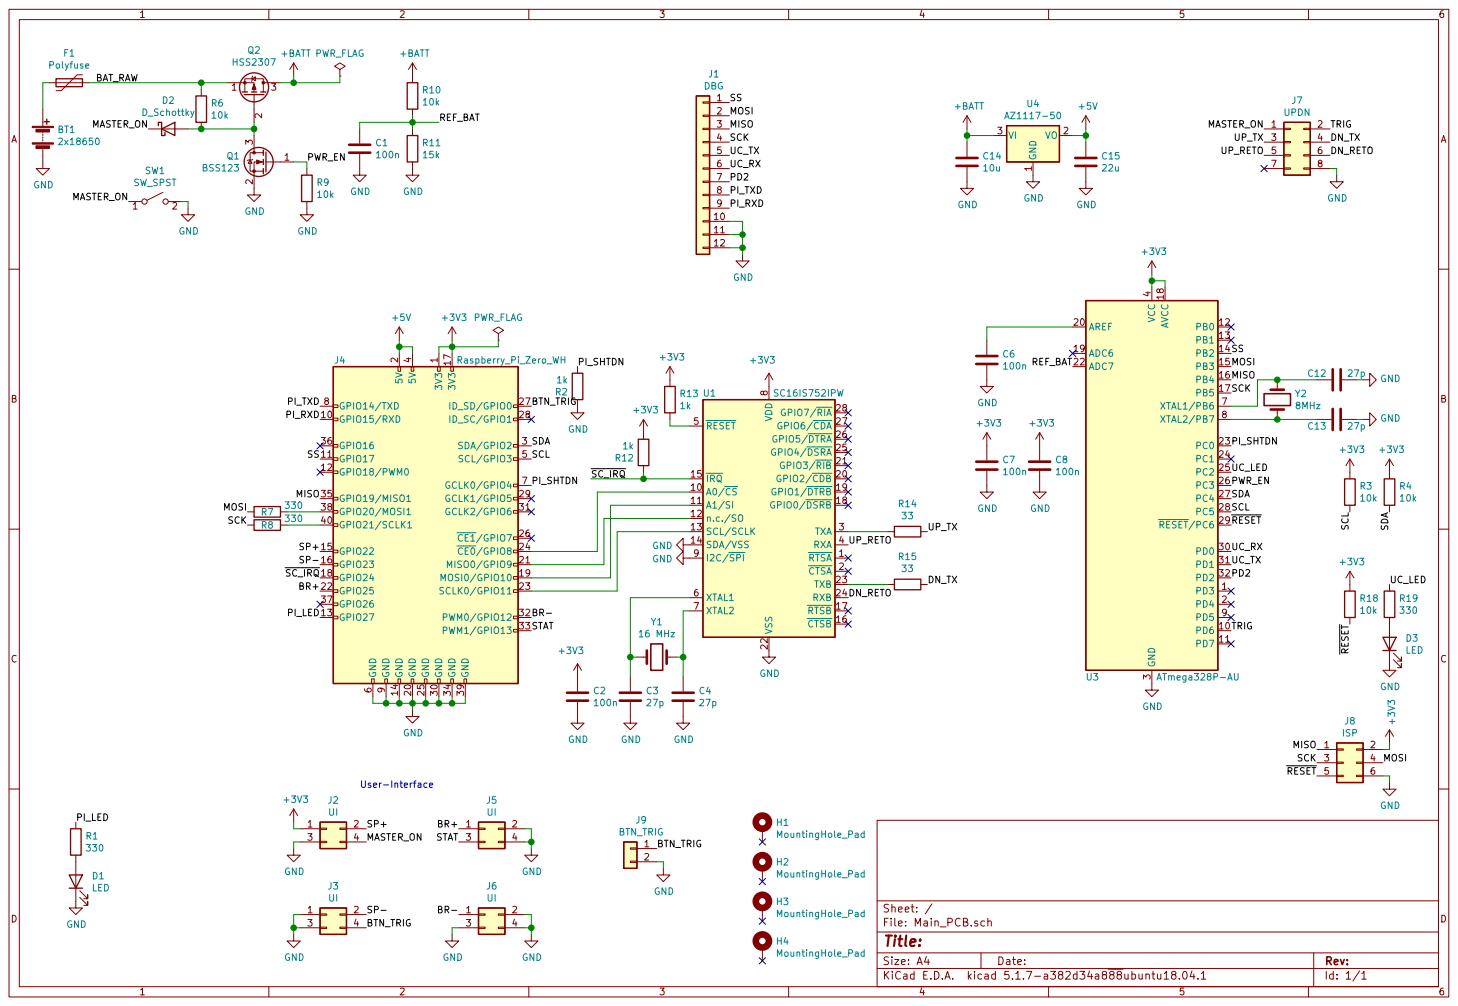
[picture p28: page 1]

1 VO 2 VI 3 U4 AZ1117-50 RTSA 1 A0/CS 10 A1/SI 11

SCL SDA User-Interface

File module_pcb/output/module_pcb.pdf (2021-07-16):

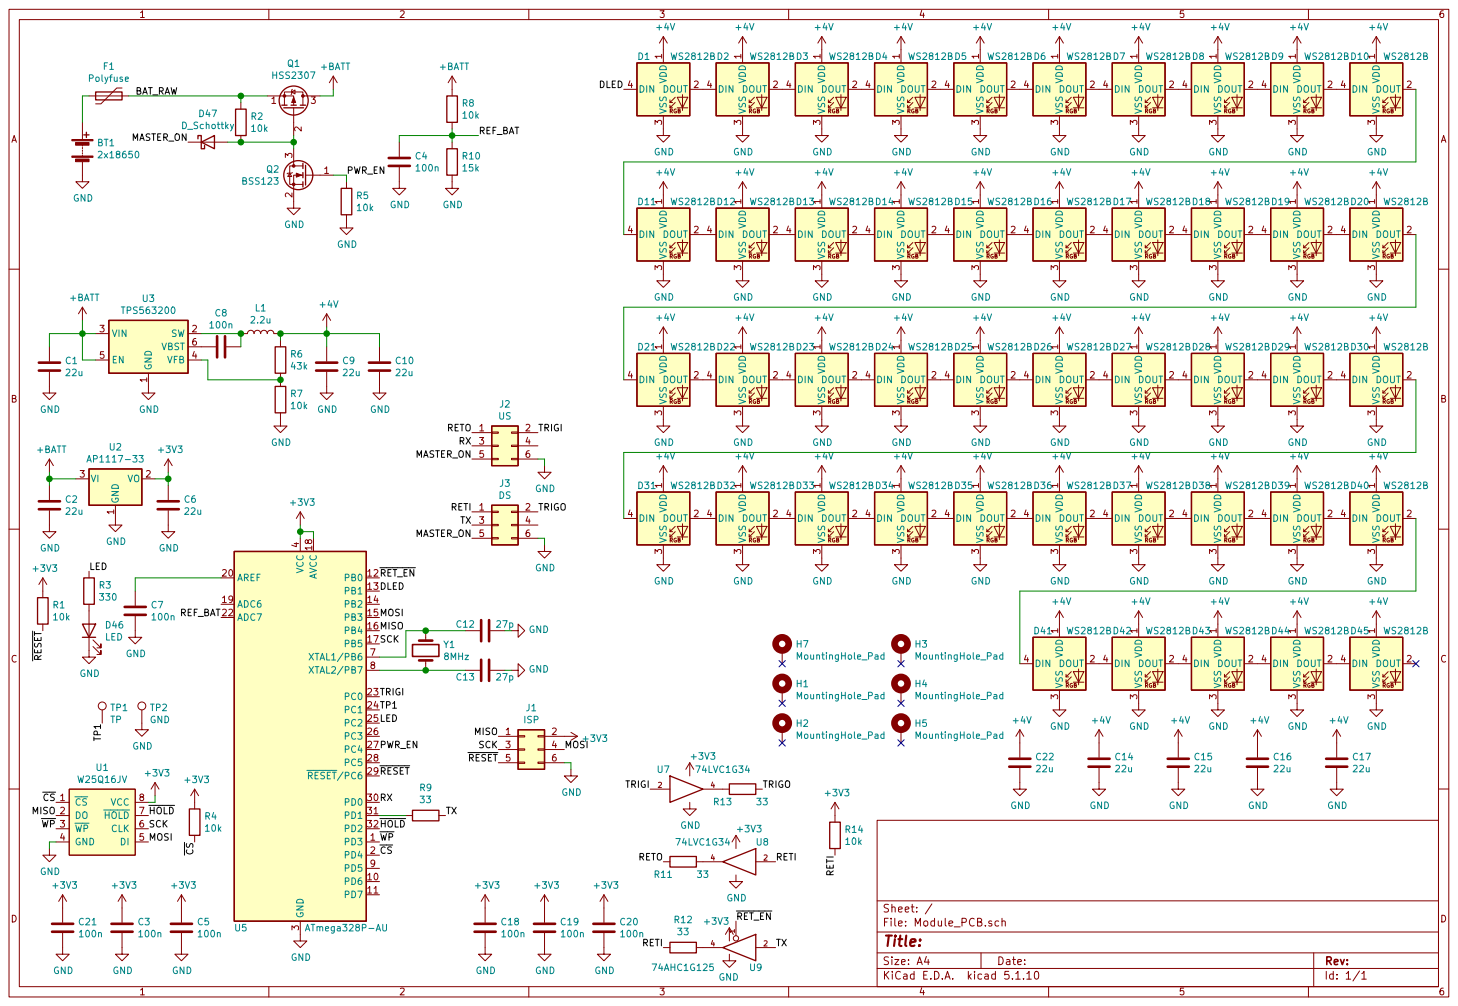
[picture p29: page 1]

1 SW 2 VIN 3 VFB 4 EN 5 VBST 6 U3 TPS563200 BT1

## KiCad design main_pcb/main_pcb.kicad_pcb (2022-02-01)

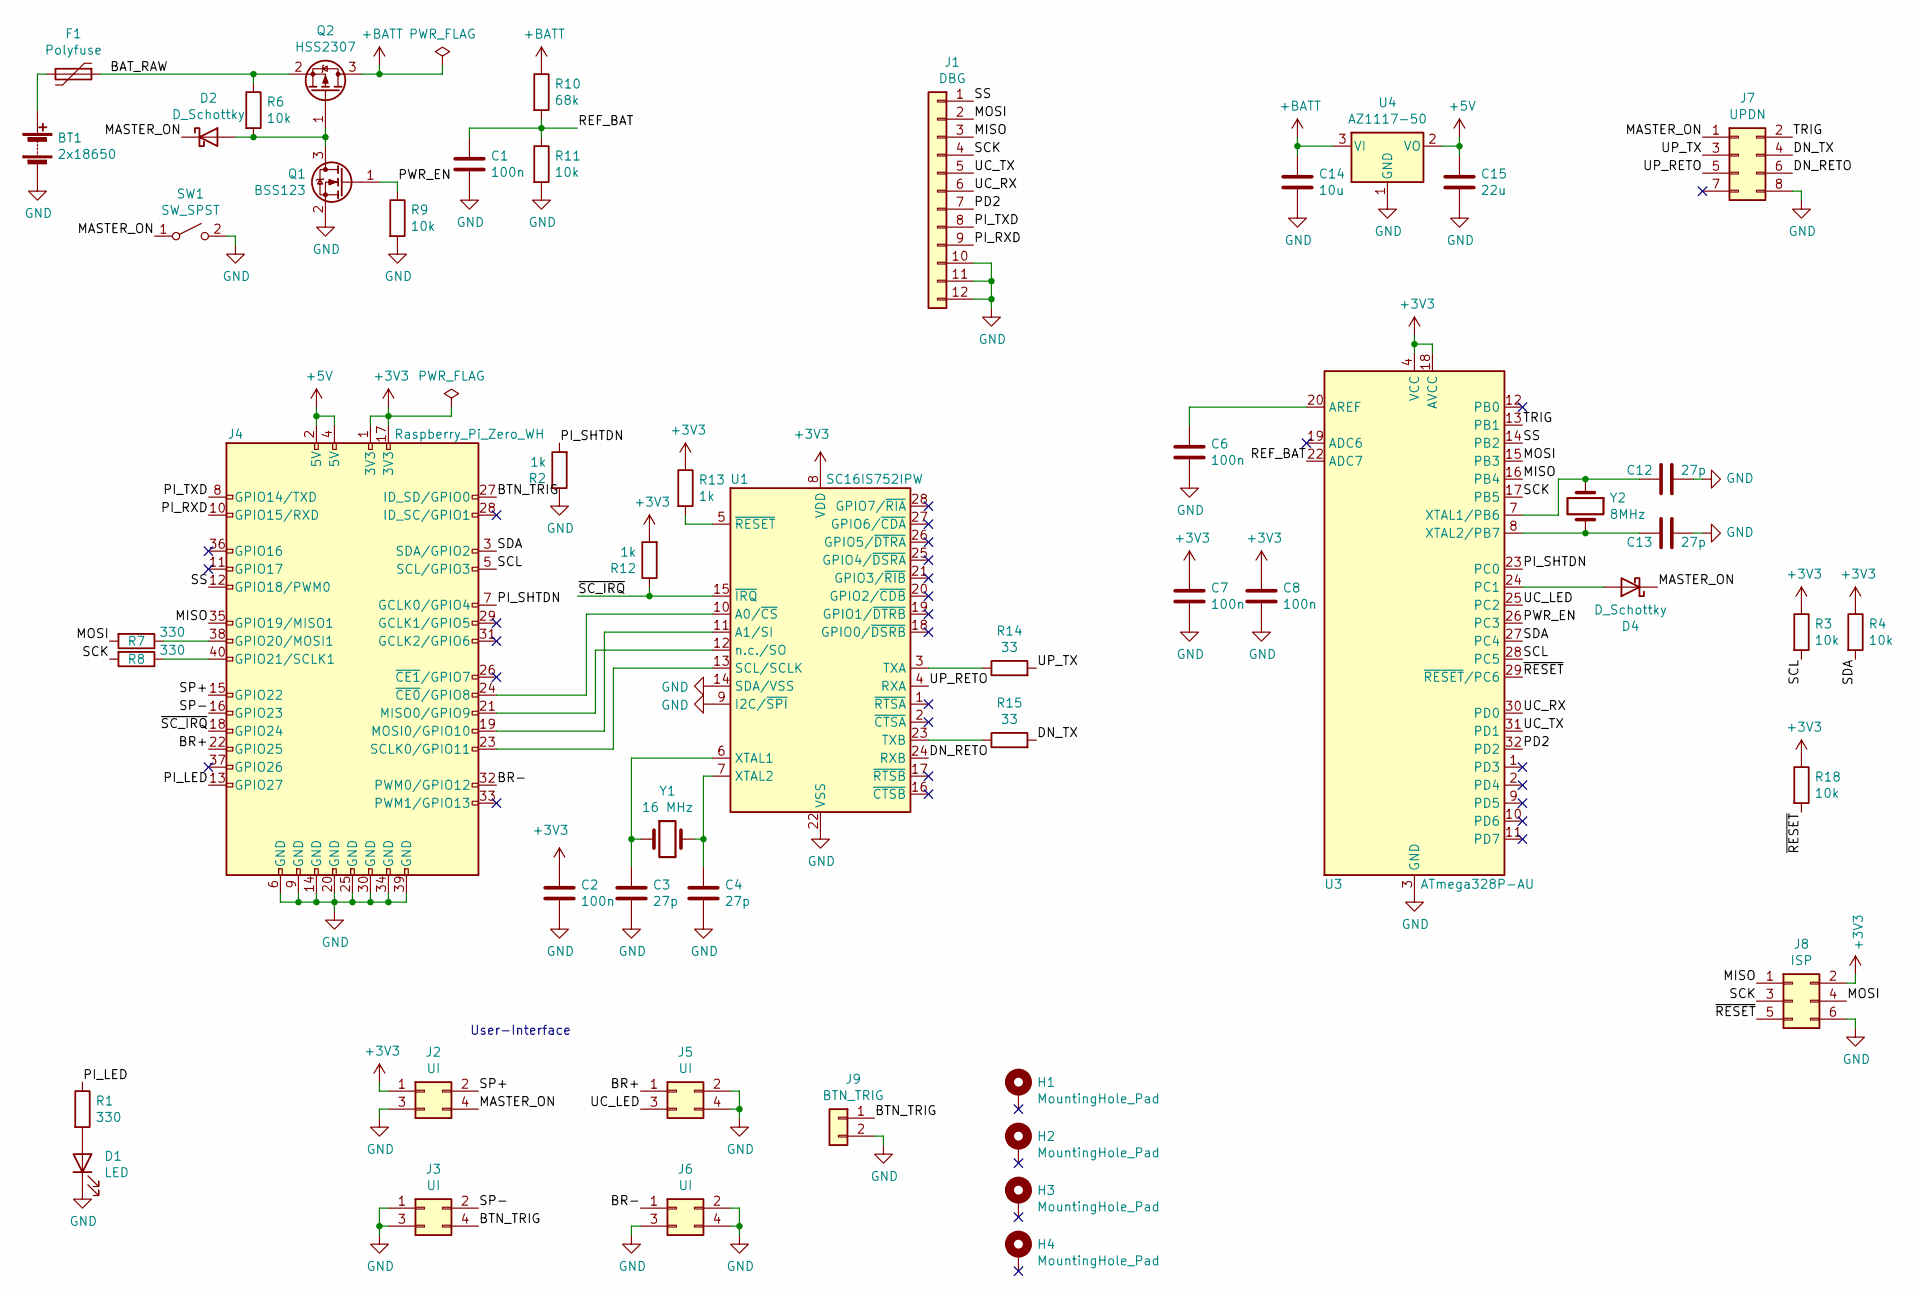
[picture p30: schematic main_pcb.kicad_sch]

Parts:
BT1: 2x18650; PinHeader_2x01_P2.54mm_Vertical; MPN DNP
C1, C2, C6, C7, C8: 100n; C_0603_1608Metric; MPN CC0603KRX7R0BB104
C3, C4, C12, C13: 27p; C_0603_1608Metric; MPN CC0603JRNPO9BN270
C14: 10u; C_1206_3216Metric; MPN CC1206KKX5R8BB106
C15: 22u; C_1206_3216Metric; MPN CC1206KKX5R8BB226
D1: LED; LED_0603_1608Metric; MPN LTST-C193KRKT-5A
D2, D4: D_Schottky; D_SOD-123; MPN SD103AW
F1: Polyfuse; Fuse_1812_4532Metric_Castellated; MPN BSMD1812-200-30V
H1, H2, H3, H4: MountingHole_Pad; MountingHole_3.2mm_M3_Pad; MPN DNP
J1: DBG; PinHeader_1x12_P2.54mm_Vertical; MPN KH-A2541WV-12P
J2, J3, J5, J6: UI; PinHeader_2x02_P2.54mm_Vertical; MPN C66690
J4: Raspberry_Pi_Zero_WH; RPiZero; MPN C50982
J7: UPDN; PinSocket_2x04_P2.54mm_Vertical; MPN PM254V-12-08-H85
J8: ISP; IDC-Header_2x03_P2.54mm_Vertical; MPN C11214
J9: BTN_TRIG; PinHeader_1x02_P2.54mm_Vertical; MPN DNP
Q1: BSS123; SOT-23; MPN BSS123
Q2: HSS2307; SOT-23W; MPN HSS2307
R1, R7, R8: 330; R_0603_1608Metric; MPN RC0603FR-07330RL
R2, R12, R13: 1k; R_0603_1608Metric; MPN AC0603FR-071KL
R3, R4, R6, R9, R11, R18: 10k; R_0603_1608Metric; MPN RC0603JR-0710KL
R10: 68k; R_0603_1608Metric; MPN RC0603JR-0768KL
R14, R15: 33; R_0603_1608Metric; MPN RC0603FR-0733RL
SW1: SW_SPST; SW_PUSH_6mm_H8mm; MPN K2-1102DP-J4SW-04
U1: SC16IS752IPW; TSSOP-28_4.4x9.7mm_P0.65mm; MPN SC16IS752IPW,128
U3: ATmega328P-AU; TQFP-32_7x7mm_P0.8mm; MPN ATmega328P-AU
U4: AZ1117-50; SOT-223-3_TabPin2; MPN AZ1117CH-5.0TRG1
Y1: 16 MHz; Crystal_SMD_HC49-SD; MPN C16000J119
Y2: 8MHz; Crystal_SMD_HC49-SD; MPN C16000J119

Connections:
+3V3: C2.1, C7.1, C8.1, J2.1, J4.1 (3V3), J4.17 (3V3), J8.2, R3.1, R4.1, R12.2, R13.1, R18.1, U1.8 (VDD), U3.4 (VCC), U3.6 (VCC), U3.18 (AVCC)
+5V: C15.1, J4.2 (5V), J4.4 (5V), U4.2 (VO)
+BATT: C14.1, Q2.3 (D), R10.1, U4.3 (VI)
/BAT_RAW: F1.1, Q2.2 (S), R6.1
/BR+: J4.22 (GPIO25), J5.1
/BR-: J4.32 (PWM0/GPIO12), J6.1
/BTN_TRIG: J3.4, J4.27 (ID_SD/GPIO0), J9.1
/DN_RETO: J7.6, U1.24 (RXB)
/DN_TX: J7.4, R15.2
/MASTER_ON: D2.1 (K), D4.1 (K), J2.4, J7.1, SW1.1 (A)
/MISO: J1.3, J4.35 (GPIO19/MISO1), J8.1, U3.16 (PB4)
/MOSI: J1.2, J8.4, R7.2, U3.15 (PB3)
/PD2: J1.7, U3.32 (PD2)
/PI_LED: J4.13 (GPIO27), R1.1
/PI_RXD: J1.9, J4.10 (GPIO15/RXD)
/PI_SHTDN: J4.7 (GCLK0/GPIO4), R2.2, U3.23 (PC0)
/PI_TXD: J1.8, J4.8 (GPIO14/TXD)
/PWR_EN: Q1.1 (G), R9.1, U3.26 (PC3)
/REF_BAT: C1.1, R10.2, R11.1, U3.22 (ADC7)
/SCK: J1.4, J8.3, R8.2, U3.17 (PB5)
/SCL: J4.5 (SCL/GPIO3), R3.2, U3.28 (PC5)
/SDA: J4.3 (SDA/GPIO2), R4.2, U3.27 (PC4)
/SP+: J2.2, J4.15 (GPIO22)
/SP-: J3.2, J4.16 (GPIO23)
/SS: J1.1, J4.12 (GPIO18/PWM0), U3.14 (PB2)
/TRIG: J7.2, U3.13 (PB1)
/UC_LED: J5.3, U3.25 (PC2)
/UC_RX: J1.6, U3.30 (PD0)
/UC_TX: J1.5, U3.31 (PD1)
/UP_RETO: J7.5, U1.4 (RXA)
/UP_TX: J7.3, R14.2
/~RESET: J8.5, R18.2, U3.29 (~RESET/PC6)
/~SC_IRQ: J4.18 (GPIO24), R12.1, U1.15 (~IRQ)
GND: BT1.2 (-), C1.2, C2.2, C3.2, C4.2, C6.2, C7.2, C8.2, C12.1, C13.1, C14.2, C15.2, D1.1 (K), J1.10, J1.11, J1.12, J2.3, J3.1, J3.3, J4.6 (GND), J4.9 (GND), J4.14 (GND), J4.20 (GND), J4.25 (GND), J4.30 (GND), J4.34 (GND), J4.39 (GND), J5.2, J5.4, J6.2, J6.3, J6.4, J7.8, J8.6, J9.2, Q1.2 (S), R2.1, R9.2, R11.2, SW1.2 (B), U1.9 (I2C/~SPI), U1.14 (SDA/VSS), U1.22 (VSS), U3.3 (GND), U3.5 (GND), U3.21 (GND), U4.1 (GND)
unnamed: BT1.1 (+), F1.2
unnamed: C3.1, U1.6 (XTAL1), Y1.1
unnamed: C4.1, U1.7 (XTAL2), Y1.2
unnamed: C6.1, U3.20 (AREF)
unnamed: C12.2, U3.7 (XTAL1/PB6), Y2.1
unnamed: C13.2, U3.8 (XTAL2/PB7), Y2.2
unnamed: D1.2 (A), R1.2
unnamed: D2.2 (A), Q1.3 (D), Q2.1 (G), R6.2
unnamed: D4.2 (A), U3.24 (PC1)
unnamed: J4.19 (MOSI0/GPIO10), U1.11 (A1/SI)
unnamed: J4.21 (MISO0/GPIO9), U1.12 (n.c./SO)
unnamed: J4.23 (SCLK0/GPIO11), U1.13 (SCL/SCLK)
unnamed: J4.24 (~CE0/GPIO8), U1.10 (A0/~CS)
unnamed: J4.38 (GPIO20/MOSI1), R7.1
unnamed: J4.40 (GPIO21/SCLK1), R8.1
unnamed: R13.2, U1.5 (~RESET)
unnamed: R14.1, U1.3 (TXA)
unnamed: R15.1, U1.23 (TXB)

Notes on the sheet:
User-Interface

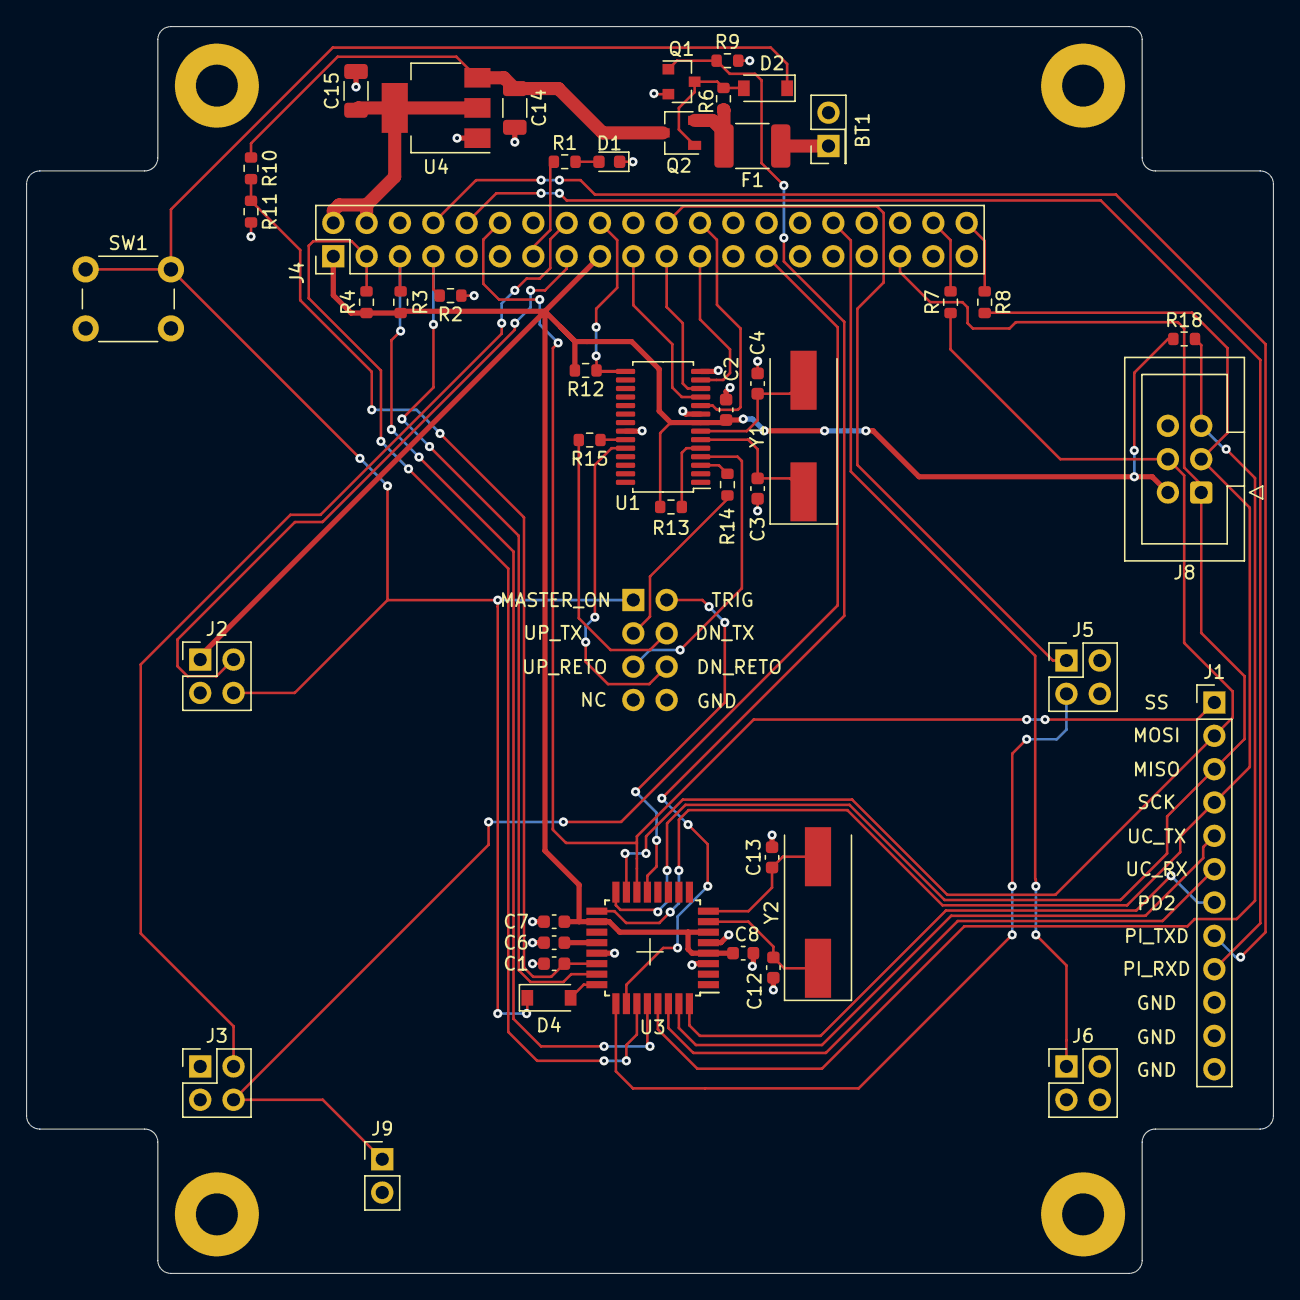
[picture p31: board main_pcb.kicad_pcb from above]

Board: 2 copper layers, 95.0 x 95.0 mm, 52 parts (1 on the bottom side), 52 nets.

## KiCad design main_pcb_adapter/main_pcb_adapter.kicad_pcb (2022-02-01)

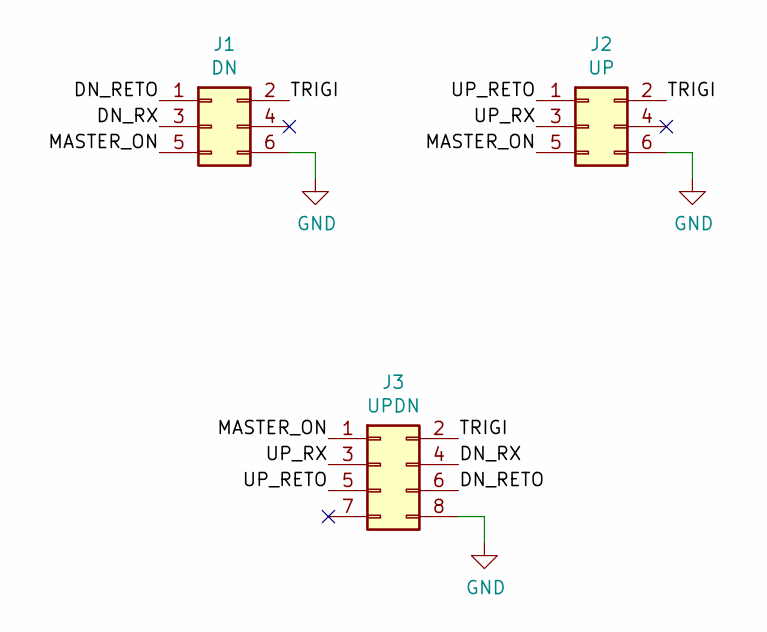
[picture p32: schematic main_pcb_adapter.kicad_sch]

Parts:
J1: DN; PinSocket_2x03_P2.54mm_Vertical; MPN DS1023-2*3SF11
J2: UP; PinSocket_2x03_P2.54mm_Vertical; MPN DS1023-2*3SF11
J3: UPDN; PinHeader_2x04_P2.54mm_Vertical; MPN B-2100S08P-B110

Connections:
/DN_RETO: J1.1, J3.6
/DN_RX: J1.3, J3.4
/MASTER_ON: J1.5, J2.5, J3.1
/TRIGI: J1.2, J2.2, J3.2
/UP_RETO: J2.1, J3.5
/UP_RX: J2.3, J3.3
GND: J1.6, J2.6, J3.8

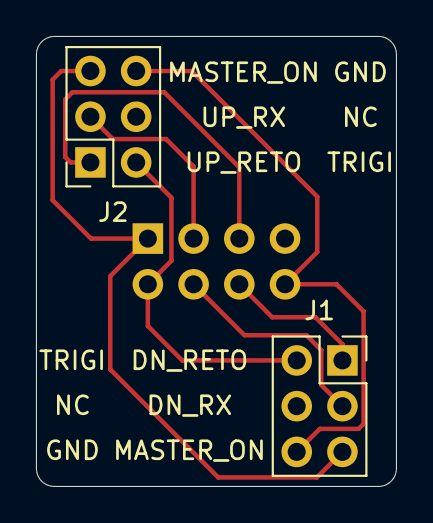
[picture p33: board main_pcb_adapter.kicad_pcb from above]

Board: 2 copper layers, 20.0 x 25.0 mm, 3 parts (1 on the bottom side), 7 nets.

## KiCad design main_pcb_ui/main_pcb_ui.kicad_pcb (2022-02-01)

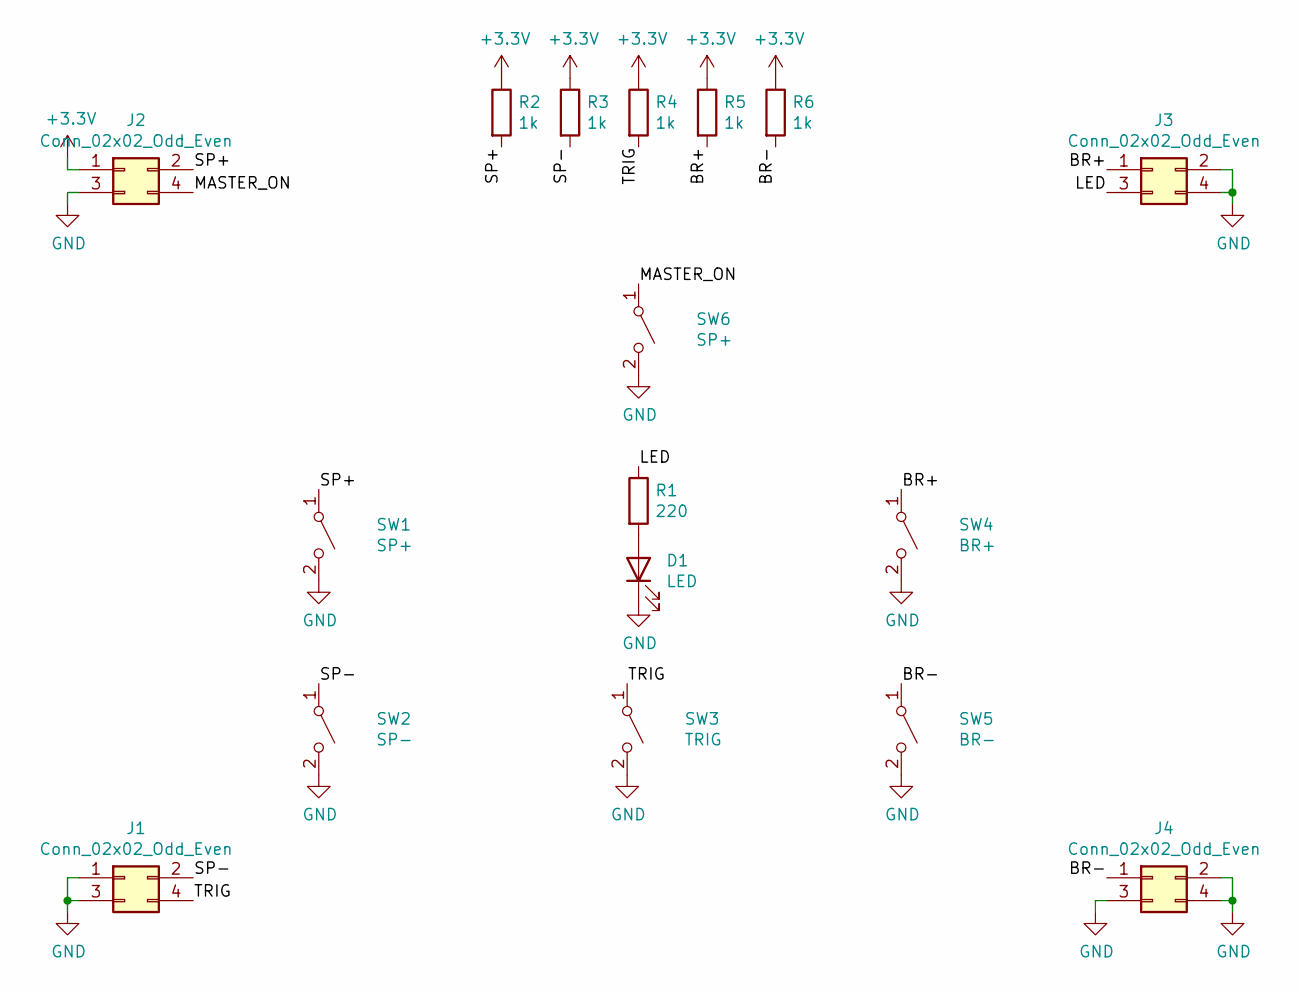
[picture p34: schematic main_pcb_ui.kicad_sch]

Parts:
D1: LED; LED_D3.0mm; MPN HL-304S9AD
J1, J3, J4: Conn_02x02_Odd_Even; PinSocket_2x02_P2.54mm_Vertical; MPN C66690
J2: Conn_02x02_Odd_Even; PinSocket_2x02_P2.54mm_Vertical; MPN DS1023-2*2SF11
R1: 220; R_0603_1608Metric; MPN CR0603FA2200G
R2, R3, R4, R5, R6: 1k; R_0603_1608Metric; MPN RC0603JR-071KL
SW1, SW6: SP+; SW_PUSH_6mm_H8mm; MPN TS4570CJ
SW2: SP-; SW_PUSH_6mm_H8mm; MPN TS4570CJ
SW3: TRIG; SW_PUSH_6mm_H8mm; MPN TS4570CJ
SW4: BR+; SW_PUSH_6mm_H8mm; MPN TS4570CJ
SW5: BR-; SW_PUSH_6mm_H8mm; MPN TS4570CJ

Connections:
+3V3: J2.1, R2.1, R3.1, R4.1, R5.1, R6.1
/BR+: J3.1, R5.2, SW4.1 (A)
/BR-: J4.1, R6.2, SW5.1 (A)
/LED: J3.3, R1.1
/MASTER_ON: J2.4, SW6.1 (A)
/SP+: J2.2, R2.2, SW1.1 (A)
/SP-: J1.2, R3.2, SW2.1 (A)
/TRIG: J1.4, R4.2, SW3.1 (A)
GND: D1.1 (K), J1.1, J1.3, J2.3, J3.2, J3.4, J4.2, J4.3, J4.4, SW1.2 (B), SW2.2 (B), SW3.2 (B), SW4.2 (B), SW5.2 (B), SW6.2 (B)
unnamed: D1.2 (A), R1.2

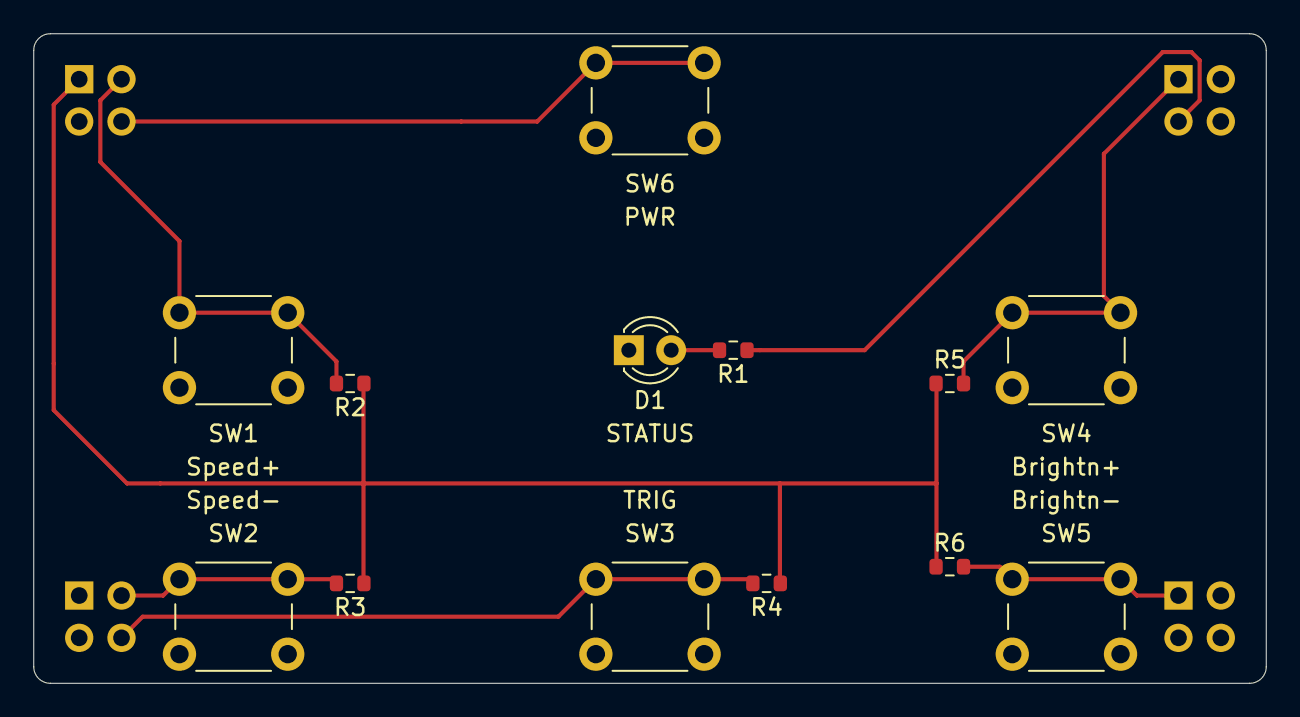
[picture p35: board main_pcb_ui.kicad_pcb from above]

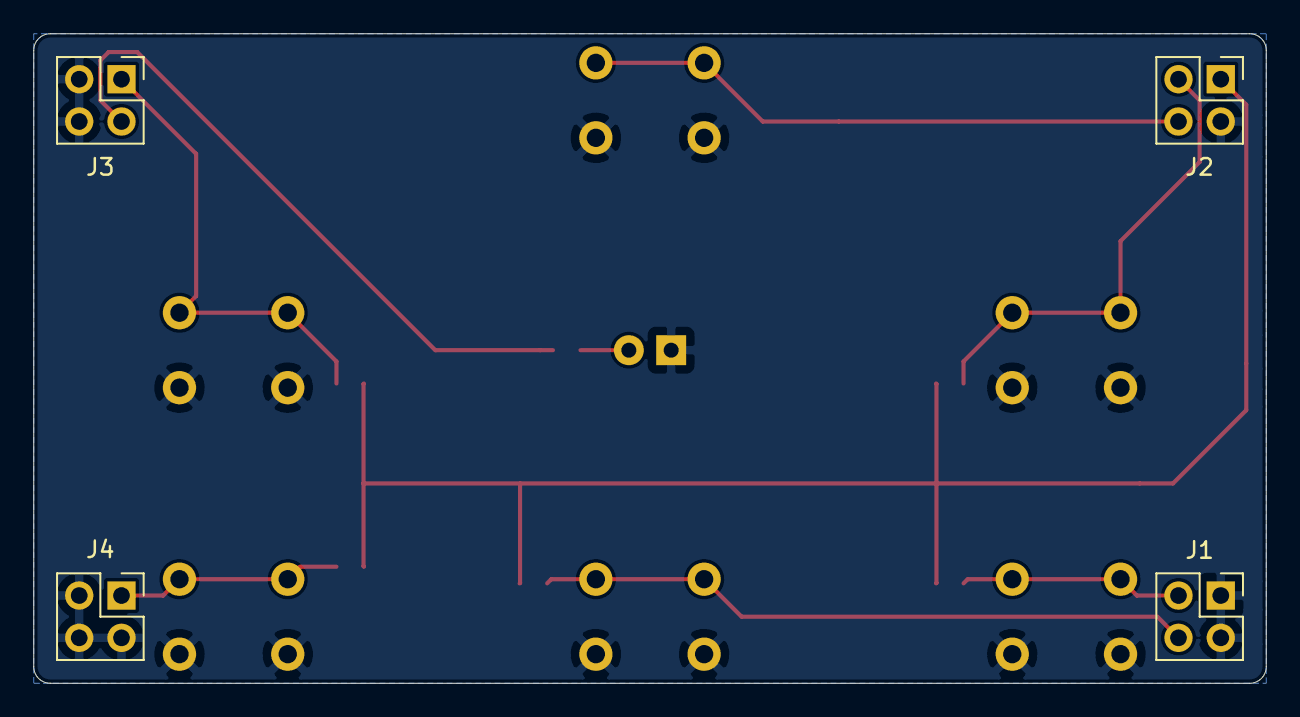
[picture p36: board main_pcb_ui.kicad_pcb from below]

Board: 2 copper layers, 74.0 x 39.0 mm, 17 parts (4 on the bottom side), 10 nets.

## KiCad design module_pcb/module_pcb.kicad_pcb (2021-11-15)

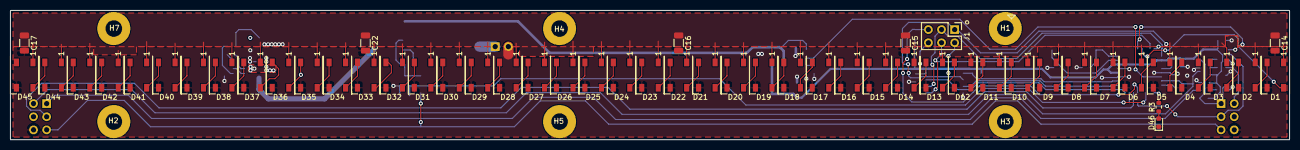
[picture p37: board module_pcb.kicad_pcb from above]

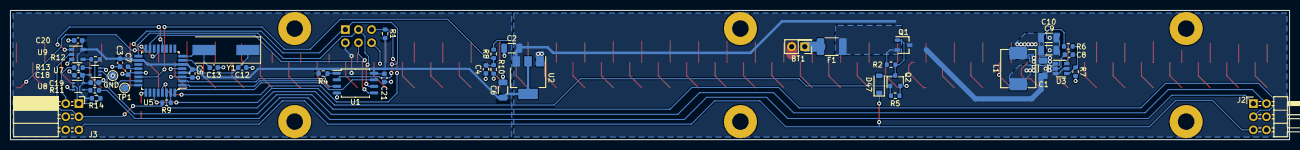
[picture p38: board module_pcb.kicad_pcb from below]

Board: 2 copper layers, 247.5 x 25.0 mm, 106 parts (47 on the bottom side), 82 nets.

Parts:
BT1: 2x18650; PinHeader_2x01_P2.54mm_Vertical
C1, C2, C6, C9, C10, C14, C15, C16, C17, C22: 22u; C_1206_3216Metric
C3, C4, C5, C7, C8, C18, C19, C20, C21: 100n; C_0603_1608Metric
C12, C13: 27p; C_0603_1608Metric
D1, D2, D3, D4, D5, D6, D7, D8, D9, D10, D11, D12, D13, D14, D15, D16, D17, D18, D19, D20, D21, D22, D23, D24, D25, D26, D27, D28, D29, D30, D31, D32, D33, D34, D35, D36, D37, D38, D39, D40, D41, D42, D43, D44, D45: WS2812B; LED_WS2812B_PLCC4_5.0x5.0mm_P3.2mm
D46: LED; LED_0603_1608Metric
D47: D_Schottky; D_SOD-123
F1: Polyfuse; Fuse_1812_4532Metric_Castellated
H1, H2, H3, H4, H5, H7: MountingHole_Pad; MountingHole_3.2mm_M3_Pad
J1: ISP; PinHeader_2x03_P2.54mm_Vertical
J2: US; PinHeader_2x03_P2.54mm_Horizontal
J3: DS; PinSocket_2x03_P2.54mm_Horizontal
L1: 2.2u; L_Abracon_ASPI-0630LR
Q1: HSS2307; SOT-23W
Q2: BSS123; SOT-23
R1, R2, R4, R5, R7, R8, R14: 10k; R_0603_1608Metric
R3: 330; R_0603_1608Metric
R6: 43k; R_0603_1608Metric
R9, R11, R12, R13: 33; R_0603_1608Metric
R10: 15k; R_0603_1608Metric
TP1: TP; TestPoint_Pad_D1.5mm
TP2: GND; TestPoint_Pad_D1.5mm
U1: W25Q16JV; SOIC-8_5.23x5.23mm_P1.27mm
U2: AP1117-33; SOT-223-3_TabPin2
U3: TPS563200; SOT-23-6
U5: ATmega328P-AU; TQFP-32_7x7mm_P0.8mm
U7, U8: 74LVC1G34; SOT-353_SC-70-5
U9: 74AHC1G125; SOT-23-5
Y1: 8MHz; Crystal_SMD_HC49-SD

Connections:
+3V3: C3.1, C5.1, C6.1, C18.1, C19.1, C20.1, C21.1, J1.2, R1.1, R4.1, R14.1, U1.8, U2.2, U5.4, U5.6, U5.18, U7.5, U8.5, U9.5
+4V: C9.1, C10.1, C14.1, C15.1, C16.1, C17.1, C22.1, D1.1, D2.1, D3.1, D4.1, D5.1, D6.1, D7.1, D8.1, D9.1, D10.1, D11.1, D12.1, D13.1, D14.1, D15.1, D16.1, D17.1, D18.1, D19.1, D20.1, D21.1, D22.1, D23.1, D24.1, D25.1, D26.1, D27.1, D28.1, D29.1, D30.1, D31.1, D32.1, D33.1, D34.1, D35.1, D36.1, D37.1, D38.1, D39.1, D40.1, D41.1, D42.1, D43.1, D44.1, D45.1, L1.2, R6.1
+BATT: C1.1, C2.1, Q1.3, R8.1, U2.3, U3.3, U3.5
/BAT_RAW: F1.1, Q1.2, R2.1
/DLED: D1.4, U5.13
/LED: R3.1, U5.25
/MASTER_ON: D47.1, J2.5, J3.5
/MISO: J1.1, U1.2, U5.16
/MOSI: J1.4, U1.5, U5.15
/PWR_EN: Q2.1, R5.1, U5.27
/REF_BAT: C4.1, R8.2, R10.1, U5.22
/RETI: J3.1, R12.2, R14.2, U8.2
/RETO: J2.1, R11.1
/RX: J2.3, U5.30
/SCK: J1.3, U1.6, U5.17
/TP1: TP1.1, U5.24
/TRIGI: J2.2, U5.23, U7.2
/TRIGO: J3.2, R13.2
/TX: J3.3, R9.2, U9.2
/~CS: R4.2, U1.1, U5.2
/~HOLD: U1.7, U5.32
/~RESET: J1.5, R1.2, U5.29
/~RET_EN: U5.12, U9.1
/~WP: U1.3, U5.1
GND: BT1.2, C1.2, C2.2, C3.2, C4.2, C5.2, C6.2, C7.2, C9.2, C10.2, C12.1, C13.1, C14.2, C15.2, C16.2, C17.2, C18.2, C19.2, C20.2, C21.2, C22.2, D1.3, D2.3, D3.3, D4.3, D5.3, D6.3, D7.3, D8.3, D9.3, D10.3, D11.3, D12.3, D13.3, D14.3, D15.3, D16.3, D17.3, D18.3, D19.3, D20.3, D21.3, D22.3, D23.3, D24.3, D25.3, D26.3, D27.3, D28.3, D29.3, D30.3, D31.3, D32.3, D33.3, D34.3, D35.3, D36.3, D37.3, D38.3, D39.3, D40.3, D41.3, D42.3, D43.3, D44.3, D45.3, D46.1, J1.6, J2.6, J3.6, Q2.2, R5.2, R7.2, R10.2, TP2.1, U1.4, U2.1, U3.1, U5.3, U5.5, U5.21, U7.3, U8.3, U9.3
unnamed: BT1.1, F1.2
unnamed: C7.1, U5.20
unnamed: C8.1, U3.6
unnamed: C8.2, L1.1, U3.2
unnamed: C12.2, U5.7, Y1.1
unnamed: C13.2, U5.8, Y1.2
unnamed: D1.2, D2.4
unnamed: D2.2, D3.4
unnamed: D3.2, D4.4
unnamed: D4.2, D5.4
unnamed: D5.2, D6.4
unnamed: D6.2, D7.4
unnamed: D7.2, D8.4
unnamed: D8.2, D9.4
unnamed: D10.2, D11.4
unnamed: D9.2, D10.4
unnamed: D11.2, D12.4
unnamed: D12.2, D13.4
unnamed: D13.2, D14.4
unnamed: D14.2, D15.4
unnamed: D15.2, D16.4
unnamed: D16.2, D17.4
unnamed: D17.2, D18.4
unnamed: D18.2, D19.4
unnamed: D19.2, D20.4
unnamed: D20.2, D21.4
unnamed: D21.2, D22.4
unnamed: D22.2, D23.4
unnamed: D23.2, D24.4
unnamed: D24.2, D25.4
unnamed: D25.2, D26.4
unnamed: D26.2, D27.4
unnamed: D27.2, D28.4
unnamed: D28.2, D29.4
unnamed: D29.2, D30.4
unnamed: D30.2, D31.4
unnamed: D31.2, D32.4
unnamed: D32.2, D33.4
unnamed: D33.2, D34.4
unnamed: D34.2, D35.4
unnamed: D35.2, D36.4
unnamed: D36.2, D37.4
unnamed: D37.2, D38.4
unnamed: D38.2, D39.4
unnamed: D39.2, D40.4
unnamed: D40.2, D41.4
unnamed: D41.2, D42.4
unnamed: D42.2, D43.4
unnamed: D43.2, D44.4
unnamed: D44.2, D45.4
unnamed: D46.2, R3.2
unnamed: D47.2, Q1.1, Q2.3, R2.2
unnamed: R6.2, R7.1, U3.4
unnamed: R9.1, U5.31
unnamed: R11.2, U8.4
unnamed: R12.1, U9.4
unnamed: R13.1, U7.4

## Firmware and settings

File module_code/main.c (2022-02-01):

#include <avr/io.h>
#include <util/delay.h>
#include "config.h"
#include "uart.h"
#include "fifo.h"
#include "ws2812b.h"
#include "flash.h"
#include "flash_sm.h"
#include <avr/interrupt.h>
#include <avr/io.h>
#include <string.h>

#define RET_EN_DDR                  DDRB
#define RET_EN_PORT                 PORTB
#define RET_EN_PIN                  0

#define PWR_EN_DDR                  DDRC
#define PWR_EN_PORT                 PORTC
#define PWR_EN_PIN                  4

#define TRIG_DDR                    DDRC  // PCINT8
#define TRIG_PORT                   PORTC
#define TRIG_IN                     PINC
#define TRIG_PIN                    0

#define LED_DDR                     DDRC
#define LED_PORT                    PORTC
#define LED_PIN                     2
#define led_on()                    LED_PORT |= (1<<LED_PIN)
#define led_off()                   LED_PORT &= ~(1<<LED_PIN)
#define led_toggle()                LED_PORT ^= (1<<LED_PIN)

#define TP_DDR                     DDRC
#define TP_PORT                    PORTC
#define TP_PIN                     1
#define tp_on()                    TP_PORT |= (1<<TP_PIN)
#define tp_off()                   TP_PORT &= ~(1<<TP_PIN)
#define tp_toggle()                TP_PORT ^= (1<<TP_PIN)

#define MESSAGE_MAGIC               0xab    // Magic word used to mark the beginning of a message

#define MESSAGE_TYPE_ADDR_SET       0x00    // Set a new module address, len=1 (new address), no ACK
#define MESSAGE_TYPE_RET_DISABLE    0x10    // Disable the return path, len=0, no ACK
#define MESSAGE_TYPE_RET_ENABLE     0x11    // Enable the return path, len=0, no ACK
#define MESSAGE_TYPE_PING           0x20    // Ping message, response with an ACK
#define MESSAGE_TYPE_STAT           0x30    // Display a status value with the LEDs, len=1
#define MESSAGE_TYPE_IMG_NEW        0x40    // Start storing a new image, len=0
#define MESSAGE_TYPE_IMG_APP        0x41    // Next image data block, len=1..256, must be 256 for all messages except the last one for an image
#define MESSAGE_TYPE_PREP           0x50    // All data transmitted to modules, prepare for trigger, len=0
#define MESSAGE_TYPE_TRIG           0x51    // Trigger a column - just for debug purposes, normal operation though TRIGI signal interrupt
#define MESSAGE_TYPE_DONE           0x52    // Playback is done, normal operation can continue
#define MESSAGE_TYPE_PIXEL_MODE     0x60    // Set the trigger mode, len=1 (trigger_mode), response with ACK
#define MESSAGE_TYPE_SHUTDOWN       0xe0    // Instruction from the host to shutdown the modules
#define MESSAGE_TYPE_ACK            0xf0    // ACK last message (also used as pong), len=0
#define MESSAGE_TYPE_NACK           0xf1    // NACK last message, len=0

#define MESSAGE_ADDR_BROADCAST      0xff   // Broadcast address, interpret and redirect to the next one
#define MESSAGE_ADDR_HOST           0xfe   // Host address

#define MESSAGE_MAX_DATA_SIZE       256    // Maximum length of data in a message

uint8_t module_addr =               0x00;  // Address of this module
uint8_t rgb_data[3*LED_COUNT];             // Buffer for next LED column
uint16_t current_column =           0;     // Current column index

typedef struct
{
    uint8_t magic;
    uint8_t type;
    uint8_t src;
    uint8_t dst;
    uint16_t len;
} __attribute__((packed)) message_header_t;

typedef struct
{
    uint8_t magic;
    uint8_t type;
    uint8_t src;
    uint8_t dst;
    uint16_t len;
    uint8_t data[MESSAGE_MAX_DATA_SIZE];
} __attribute__((packed)) message_t;

#define MESSAGE_HEADER_SIZE ((sizeof(message_t)-MESSAGE_MAX_DATA_SIZE))

void message_tx(message_t* msg)
{
    uint8_t* msg_raw = (uint8_t*)msg;
    for(uint16_t k = 0; k < MESSAGE_HEADER_SIZE + msg->len; k++)
        uart_putc(msg_raw[k]);
}

void process_message(message_t* msg);
void transmit_response(uint8_t success);
void display_status(uint8_t status);
void debug_flash();
void debug_flash_sm();

#define MIN_VOLTAGE      6000   // minimum voltage (mV), below this value the module will turn itself off
uint16_t get_voltage();

static message_t msg;  // message buffer
static uint8_t pixel_mode = 1;  // pixel mode enabled if true
static bool shutdown = false;  // True if the host requested a shutdown

int main()
{
    // Init GPIOs
    RET_EN_PORT |= (1<<RET_EN_PIN);  // Disable return path by default
    RET_EN_DDR |= (1<<RET_EN_PIN);
    PWR_EN_PORT &= (1<<PWR_EN_PIN);  // Disable own power supply by default
    PWR_EN_DDR |= (1<<PWR_EN_PIN);
    LED_DDR |= (1<<LED_PIN);
    TP_DDR |= (1<<TP_PIN);
    led_on();

    // Before we do anything, we wait 2 seconds, then turn on the power supply for ourself
    _delay_ms(2000);
    PWR_EN_PORT |= (1<<PWR_EN_PIN);

    ws2812b_init();
    uart_init();
    flash_init();
    flash_sm_init();
    sei();

    // Set up battery monitoring ADC
    ADMUX = (1<<REFS0) | (1<<REFS1) | 7; // 1.1V internal reference, ADC7 source
    ADCSRA = (1<<ADEN) | (1<<ADPS2) | (1<<ADPS1) | (1<<ADPS0);  // Enable, 1/128 prescaler
    get_voltage(); // Dummy read
    _delay_ms(10); // Wait a moment for the bandgap voltage to stabilize

    // Disable all LEDs
    display_status(0);

    // Set up trigger interrupt
    TRIG_DDR &= ~(1<<TRIG_PIN);
    TRIG_PORT |= (1<<TRIG_PIN); // Enable pull-up
    PCICR |= (1<<PCIE1);
    PCMSK1 |= (1<<TRIG_PIN);

    // Test flash
    //debug_flash()

    // Test flash state machine
    //debug_flash_sm();

    //uint8_t counter = 0;
    while(1)
    {
        // Wait for the magic word
        while(fifo_popc(&uart_in_fifo) != MESSAGE_MAGIC)
        {
            // Run flash state machine to free unused memory
            flash_sm_tick();

            // Read voltage and shutdown the module, if it is too low
            uint16_t voltage = get_voltage();
            if(voltage < MIN_VOLTAGE || shutdown)
            {
                cli();
                led_off();
                PWR_EN_PORT &= ~(1<<PWR_EN_PIN);
                // After cutting our own power, we do nothing any more to prevent any undefined states
                while(1);
            }
        }
        msg.magic = MESSAGE_MAGIC;

        // Read the rest of the header, exclude magic word
        uint8_t* header = ((uint8_t*)&msg) + 1;
        for(uint8_t k = 0; k < MESSAGE_HEADER_SIZE - 1; k++)
            header[k] = fifo_popc_block(&uart_in_fifo);

        // Check data length
        if(msg.len > MESSAGE_MAX_DATA_SIZE)
            continue;

        // Read the data
        for(uint16_t k = 0; k < msg.len; k++)
            msg.data[k] = fifo_popc_block(&uart_in_fifo);

        // Got a complete message, interpret it
        bool message_for_this_module = false;
        if(msg.dst == module_addr || msg.dst == MESSAGE_ADDR_BROADCAST)
        {
            // process_message may change the module address, so we have to remember
            // if this message was for this module or not
            message_for_this_module = true;
            process_message(&msg);
        }

        // If this message is not for this module or is a broadcast message,
        // forward it to the next module
        if(!message_for_this_module || msg.dst == MESSAGE_ADDR_BROADCAST)
            message_tx(&msg);
    }
}

void process_message(message_t* msg)
{
    uint8_t status;
    switch(msg->type)
    {
    case MESSAGE_TYPE_ADDR_SET:
        if(msg->len != 1)
            return transmit_response(0);
        // Set the current module address
        module_addr = msg->data[0];
        return;  // don't send ACK
    case MESSAGE_TYPE_RET_DISABLE:
        if(msg->len != 0)
            return transmit_response(0);
        // Disable the RET* transmitter, we don't know how many modules are after us
        RET_EN_PORT |= (1<<RET_EN_PIN);
        return;  // don't send an ACK, no one will get it anyways
    case MESSAGE_TYPE_RET_ENABLE:
        if(msg->len != 0)
            return transmit_response(0);
        // Enable the RET* transmitter
        RET_EN_PORT &= ~(1<<RET_EN_PIN);
        break;
    case MESSAGE_TYPE_PING:
        // Fall through to send ACK
        break;
    case MESSAGE_TYPE_STAT:
        if(msg->len != 1)
            return transmit_response(0);
        status = msg->data[0];
        display_status(status);
        break;
    case MESSAGE_TYPE_IMG_NEW:
        // Start a new image
        flash_sm_image_new();
        break;
    case MESSAGE_TYPE_IMG_APP:
        // Append new image data to the current image
        flash_sm_image_append(msg->data, msg->len);
        break;
    case MESSAGE_TYPE_PREP:
        // Turn off the LED
        led_off();
        // Put the flash in continuous read mode and read the first column
        flash_sm_read_image_start();
        flash_sm_read_image_data(rgb_data, LED_COUNT*3);
        break;
    case MESSAGE_TYPE_PIXEL_MODE:
        if(msg->len != 1)
            return transmit_response(0);
        pixel_mode = msg->data[0];
        break;
    case MESSAGE_TYPE_TRIG:
        // Send data to LEDs and load new data after that
        ws2812b_send_column(rgb_data, LED_COUNT);
        flash_sm_read_image_data(rgb_data, LED_COUNT*3);
        break;
    case MESSAGE_TYPE_DONE:
        // Turn the LED on
        led_on();
        // Playback is done, disable read mode so we will continue erasing the flash
        flash_sm_read_image_stop();
        // Also make sure that all LEDs are turned off
        display_status(0);
        break;
    case MESSAGE_TYPE_SHUTDOWN:
        shutdown = true;
        break;
    }

    // Transmit an ACK
    transmit_response(1);
}

void transmit_response(uint8_t success)
{
    message_header_t msg;
    msg.magic = MESSAGE_MAGIC;
    msg.type = success?MESSAGE_TYPE_ACK:MESSAGE_TYPE_NACK;
    msg.len = 0;
    msg.dst = MESSAGE_ADDR_HOST;
    msg.src = module_addr;
    message_tx((message_t*)&msg);
}

void display_status(uint8_t status)
{
    for(uint8_t k = 0; k < 8; k++)
    {
        rgb_data[k*3+0] = ((status<<k)&0x80)>>2;
        rgb_data[k*3+1] = 0;
        rgb_data[k*3+2] = 0;
    }
    for(uint8_t k = 8*3; k < LED_COUNT*3; k++)
        rgb_data[k] = 0;
    ws2812b_send_column(rgb_data, LED_COUNT);
    _delay_ms(1);
}

extern uint8_t reading;  // Reading status from flash_sm.c
ISR(PCINT1_vect)
{
    // Make sure we are in reading mode
    if(!reading)
        return;

    if(pixel_mode)
    {
        // Update pixels in any case
        ws2812b_send_column(rgb_data, LED_COUNT);
        ws2812b_trigger();

        if(!(TRIG_IN & (1<<TRIG_PIN)))
        {
            // Load zeros on falling edge
            for(uint8_t i = 0; i < LED_COUNT*3; i++)
                rgb_data[i] = 0;
        }
        else
        {
            // Load image data on rising edge
            flash_sm_read_image_data(rgb_data, LED_COUNT*3);
        }
    }
    else
    {
        // On falling edge update pixels and load new data
        if(!(TRIG_IN & (1<<TRIG_PIN)))
        {
            ws2812b_send_column(rgb_data, LED_COUNT);
            ws2812b_trigger();
            flash_sm_read_image_data(rgb_data, LED_COUNT*3);
        }
        // Do nothing on rising edge when not in pixel mode
    }
}

void debug_flash_sm()
{
    // DEBUG - Test flash image write and automatic erase
    uint8_t data[256];
    RET_EN_PORT &= ~(1<<RET_EN_PIN);  // Enable return path for debug
    _delay_ms(200);  // wait a moment for the uart line to stabilize
    flash_sm_init();
    flash_sm_print_state();
    _delay_ms(100);
    flash_sm_print_state();
    flash_sm_tick();
    flash_sm_print_state();
    flash_sm_image_new();
    flash_sm_print_state();
    flash_sm_image_append(data, 256);
    flash_sm_print_state();
    flash_sm_image_new();
    flash_sm_print_state();
    flash_sm_image_append(data, 256);
    flash_sm_print_state();
    for(int i = 0; i < 33; i++)
        flash_sm_image_append(data, 256);
    flash_sm_print_state();
}

void debug_flash_sm2()
{
    uint8_t data[256];
    data[0] = 42;
    data[1] = 43;
    data[2] = 44;
    flash_sm_init();
    flash_sm_print_state();
    flash_sm_tick();
    flash_sm_print_state();
    flash_sm_image_new();
    flash_sm_image_append(data, 256);
    flash_sm_image_append(data, 16);
    flash_sm_print_state();
    flash_sm_read_image_start();
    flash_sm_print_state();
    data[0] = 1;
    data[1] = 2;
    data[2] = 3;
    flash_sm_read_image_data(data, 45*3);
    uart_putcc("data[0]: ");
    uart_putu32(data[0]);
    uart_putcc(", data[1]: ");
    uart_putu32(data[1]);
    uart_putcc(", data[2]: ");
    uart_putu32(data[2]);
    uart_putcc("\n");
}

void debug_flash()
{
    uint8_t data[256];
    // DEBUG - Test flash block write and read process
    RET_EN_PORT &= ~(1<<RET_EN_PIN);  // Enable return path for debug
    uart_putcc("\r\nStarted\r\n");
    flash_chip_erase();
    uart_putcc("Chip erased\r\n");
    strcpy((char*)data, "Hello world!\r\n");
    flash_write_page(1, data);
    uart_putcc("Write done\r\n");
    for(int i = 0; i < 256; i++)
        data[i] = 'x';
    flash_read_cont_start(1);
    uart_putcc("Read started\r\n");
    while(1)
    {
        uint8_t data;
        flash_read_cont_read(&data, 1);
        if(data == 0 || data == 0xff)
            break;
        uart_putc(data);
    }
    flash_read_cont_stop();
    uart_putcc("Read done\r\n");
}

uint16_t get_voltage()
{
    ADCSRA |= (1<<ADSC);  // Start conversion
    while(ADCSRA & (1<<ADSC));  // Wait for completion
    uint16_t adc_val = ADCW;
    ADCSRA |= (1<<ADIF); // Clear interrupt flag

    // convert ADC value to voltage, reference is 1.1V, voltage divider 10/78
    uint16_t voltage = (uint16_t)(adc_val*8.37);
    return voltage;
}

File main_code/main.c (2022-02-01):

#include <avr/io.h>
#include <avr/interrupt.h>
#include <util/delay.h>
#include <util/atomic.h>

#define MIN_VOLTAGE      6000   // minimum voltage (mV), below this value the module will turn itself off

#define LED_DDR          DDRC
#define LED_PORT         PORTC
#define LED_PIN          2
#define led_init()       LED_DDR |= (1<<LED_PIN)
#define led_on()         LED_PORT |= (1<<LED_PIN)
#define led_off()        LED_PORT &= ~(1<<LED_PIN)
#define led_toggle()     LED_PORT ^= (1<<LED_PIN)

#define PI_SHTDN_DDR     DDRC
#define PI_SHTDN_PORT    PORTC
#define PI_SHTDN_PIN     0
#define pi_shtdn_init()  PI_SHTDN_DDR |= (1<<PI_SHTDN_PIN)
#define pi_shtdn_low()   PI_SHTDN_PORT &= ~(1<<PI_SHTDN_PIN)
#define pi_shtdn_high()  PI_SHTDN_PORT |= (1<<PI_SHTDN_PIN)

#define MASTER_ON_DDR    DDRC
#define MASTER_ON_PORT   PORTC
#define MASTER_ON_VALUE  PINC
#define MASTER_ON_PIN    1
#define master_on_init() MASTER_ON_DDR &= ~(1<<MASTER_ON_PIN)
#define master_on_pu()   MASTER_ON_PORT |= (1<<MASTER_ON_PIN)
#define master_on_val()  (MASTER_ON_VALUE & (1<<MASTER_ON_PIN))

#define PWR_ON_DDR     DDRC
#define PWR_ON_PORT    PORTC
#define PWR_ON_PIN     3
#define pwr_on_init()  PWR_ON_DDR |= (1<<PWR_ON_PIN)
#define pwr_on_low()   PWR_ON_PORT &= ~(1<<PWR_ON_PIN)
#define pwr_on_high()  PWR_ON_PORT |= (1<<PWR_ON_PIN)

static uint8_t spi_byte_cnt = 0;

typedef struct __attribute__((__packed__)) {
    uint8_t command;
    uint16_t period;
    uint16_t on_time;
    uint16_t trigger_count;
} command_t;
static volatile command_t command_buffer;
static uint8_t *command_buffer_data = (uint8_t*)&command_buffer;
#define COMMAND_START_TRIGGER   0x01
#define COMMAND_STOP_TRIGGER    0x02
#define COMMAND_INFINITE_REPEAT 0x04

typedef struct __attribute__((__packed__)) {
    uint8_t magic0;
    uint16_t voltage;
    uint16_t trigger_counter;
    uint8_t shutdown;
    uint8_t magic1;
} answer_t;
static volatile answer_t answer;
static uint8_t *answer_data = (uint8_t*)&answer;

// Timer
static uint16_t timer_period;
static uint16_t timer_on_time;
static uint16_t timer_trigger_count;
static uint8_t timer_infinite_repeat;
#define timer_on() TCCR1B |= (1<<CS11)
#define timer_off() TCCR1B &= ~(1<<CS11)
void timer_init()
{
    DDRB |= (1<<1); // Set OC1A as output
    TIMSK1 = (1<<TOIE1); // Enable overflow interrupt
    TCCR1A = (1<<COM1A1) | (1<<WGM11);
    TCCR1B = (1<<WGM12) | (1<<WGM13);  // Fast PWM mode, TOP = ICR1, no clock
    ICR1 = timer_period - 1;
    OCR1A = timer_on_time - 1;
    answer.trigger_counter = timer_trigger_count;
}

uint16_t get_voltage()
{
    ADCSRA |= (1<<ADSC);  // Start conversion
    while(ADCSRA & (1<<ADSC));  // Wait for completion
    uint16_t adc_val = ADC;
    ADCSRA |= (1<<ADIF); // Clear interrupt flag

    // convert ADC value to voltage, reference is 1.1V, voltage divider 10/78
    uint16_t voltage = (uint16_t)(adc_val*8.37);
    return voltage;
}

int main()
{
    led_init();
    pi_shtdn_init();
    pi_shtdn_low();
    master_on_init();
    master_on_pu();
    pwr_on_init();
    pwr_on_low();

    // Wait 2 seconds before we actually turn on the power while flashing the LED
    for(int i = 0; i < 20; i++)
    {
        _delay_ms(100);
        led_toggle();
    }
    led_on();
    pwr_on_high();

    // Set up SPI ~SS pin change interrupt
    PORTB |= (1<<2); // Enable pull-up
    PCICR |= (1<<PCIE0);
    PCMSK0 |= (1<<2);

    // Set up SPI slave
    DDRB |= (1<<4); // Set MISO as output
    SPCR = (1<<SPIE) | (1<<SPE);

    // Set up battery monitoring ADC
    ADMUX = (1<<REFS0) | (1<<REFS1) | 7; // 1.1V internal reference, ADC7 source
    ADCSRA = (1<<ADEN) | (1<<ADPS2) | (1<<ADPS1) | (1<<ADPS0);  // Enable, 1/128 prescaler
    get_voltage(); // Dummy read
    _delay_ms(10); // Wait a moment for the bandgap voltage to stabilize

    // Set up trigger timer at OC0A output
    timer_period = 1000;
    timer_on_time = 500;
    timer_trigger_count = 10;
    timer_infinite_repeat = 0;
    timer_init();
    timer_on();  // Do a dummy sequence to prepare the OC1A pin

    answer.shutdown = 0;
    answer.magic0 = 0x31;
    answer.magic1 = 0x41;
    sei();

    uint16_t shutdown_counter = 0;

    while(1)
    {
        // Atomically update the battery voltage and only if we are not selected at the moment
        // This will prevent an update of the voltage while we are currently transmitting it
        uint16_t voltage = get_voltage();
        if(PINB & (1<<2))
        {
            answer.voltage = voltage;
        }
        if(voltage < MIN_VOLTAGE || shutdown_counter > 2000)
        {
            // Request a shutdown of the Pi
            answer.shutdown = 1;
            pi_shtdn_high();
            led_off();
            // Wait 15 seconds before we actually turn on the power while flashing the LED
            for(int i = 0; i < 150; i++)
            {
                _delay_ms(100);
                led_toggle();
            }
            led_off();
            pwr_on_low();
        }
        if(!master_on_val())
            shutdown_counter++;
        else
            shutdown_counter = 0;
        _delay_ms(1);
    }
    return 0;
}

// SPI transfer complete interrupt
ISR(SPI_STC_vect)
{
    // Save data to buffer
    command_buffer_data[spi_byte_cnt] = SPDR;

    // Write next byte and increment byte counter
    // spi_byte_cnt is still 0 after the first byte has been received, so we transmit
    // answer_data[spi_byte_cnt+1]
    if(spi_byte_cnt + 1 < sizeof(command_t))
    {
        SPDR = answer_data[spi_byte_cnt+1];
        spi_byte_cnt++;
    }
}

// PB2 aka ~SS pin toggle interrupt
ISR(PCINT0_vect)
{
    // On selection, write the first byte (magic0)
    if(!(PINB & (1<<2)))
    {
        SPDR = answer_data[0];
        return;
    }
    
    // Reset byte count
    spi_byte_cnt = 0;

    // Interprete the SPI RX buffer
    if(command_buffer.command)
    {
        timer_period = command_buffer.period;
        timer_on_time = command_buffer.on_time;
        timer_trigger_count = command_buffer.trigger_count;
    }
    timer_infinite_repeat = !!(command_buffer.command & COMMAND_INFINITE_REPEAT);
    if(command_buffer.command & COMMAND_START_TRIGGER)
    {
        timer_init();
        timer_on();
    }
    if(command_buffer.command & COMMAND_STOP_TRIGGER)
    {
        timer_off();
    }
}

// Timer 1 overflow interrupt
ISR(TIMER1_OVF_vect)
{
    led_toggle();
    answer.trigger_counter--; // Count the columns
    if(!answer.trigger_counter)
    {
        // Reset counter or turn off trigger signal
        if(timer_infinite_repeat) {
            answer.trigger_counter = timer_trigger_count;
        } else {
            timer_off();
        }
    }
}

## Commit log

2021-06-27 First version of the module PCB
    [LEDStripModule.kicad_pcb, LEDStripModule.sch]
2021-06-27 Fixed pin header part numbers
    [LEDStripModule.sch]
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2021-06-27 Added MPN for isp header Exported BOM
    [LEDStripModule.csv, LEDStripModule.sch]
2021-06-27 Changed name from LEDStripModule to Module_PCB of the Kicad project
    [Module_PCB.csv, Module_PCB.kicad_pcb, Module_PCB.sch]
2021-06-27 Changed ISP header back to 2x3
    [Module_PCB.csv, Module_PCB.kicad_pcb, Module_PCB.sch]
2021-06-27 Fixed MPN
    [Module_PCB.sch]
2021-06-27 Fixed connector position
    [Module_PCB.kicad_pcb]
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2021-06-28 Changed the battery protection method and added a turn-on wire for the master
    [Module_PCB.csv, Module_PCB.kicad_pcb, Module_PCB.sch]
2021-06-29 Added a polyfuse, fixes #4
    [Module_PCB.csv, Module_PCB.kicad_pcb, Module_PCB.sch]
2021-06-29 Added voltage divider to measure the battery voltage
    [Module_PCB.csv, Module_PCB.kicad_pcb, Module_PCB.sch]
2021-06-29 Routed two signals which were forgotten
    [Module_PCB.kicad_pcb, Module_PCB.sch]
2021-07-01 fix defconfig and add genimage config
    also fixes a typo in the rootfs directory name
    [genimage-LEDStrip_pi.cfg]
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2021-07-04 Moved the holes of the module PCB for a better mechanically fit
    [Module_PCB.kicad_pcb]
2021-07-04 Moved drill holes for better mechanical design
    [Module_PCB.kicad_pcb]
2021-07-04 Few smaller fixes in Module_PCB Export of Gerber files, used for first prototype
    [Module_PCB-B_Cu.gbl, Module_PCB-B_Mask.gbs, Module_PCB-B_Paste.gbp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]
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2021-07-06 Fixed bug ToggleSwitch preventing the correct text rendering of current status.
2021-07-07 Fixed typo: prograss_value -> progress_value
    [blinkybar.py]
2021-07-08 change rootfs to squashfs
    We want to have a readonly rootfs in order not to burden the sd card too
    much. Squashfs is the goto choice for that.
    [genimage-LEDStrip_pi.cfg]
2021-07-08 add additional ext4 partition
    This commit adds an empty third partition of 30 MB. It's an ext4
    partition to allow quick changes during development.
    [genimage-LEDStrip_pi.cfg]
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2021-07-09 Don't fail if serial port not available
    [blinkybar.py]
2021-07-09 Fixed image re-scaling bug
    [blinkybar.py]
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2021-07-09 - Fixed bug preventing emission of new values from slider click - Added functionality to change color temperature
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2021-07-10 Added system_error_msg to the API to indicate a critical system error to the user
    [blinkybar.py]
2021-07-10 Added copper pour in bottom layer to prevent PCB warping, fixes #11 Moved the large copper pours a bit away from the border to prevent shorts
    [Module_PCB-B_Cu.gbl, Module_PCB-B_Mask.gbs, Module_PCB-B_Paste.gbp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]
2021-07-10 Improved battery connection and added Pin-1 indicator for the ISP header
    [Module_PCB-B_Cu.gbl, Module_PCB-B_Mask.gbs, Module_PCB-B_Paste.gbp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]
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2021-07-11 Updated atmega crystal to 8 MHz
    [Module_PCB.csv, Module_PCB.kicad_pcb, Module_PCB.sch]
2021-07-11 Changed 10k and 15k resistors to 1% variants
    [Module_PCB.csv, Module_PCB.sch]
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2021-07-11 Small fix for the mirror flag
    [blinkybar.py]
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2021-07-14 Added MPN for 3x2 angled inter-module connectors
    [Module_PCB.csv, Module_PCB.sch]
2021-07-14 Fixed wrong symbol, wrong pinout, and wrong footprint of p-channel power mosfet
    [Module_PCB-B_Cu.gbl, Module_PCB-B_Mask.gbs, Module_PCB-B_Paste.gbp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]
2021-07-14 Fixed missing PWR_EN signal
    [Module_PCB-B_Cu.gbl, Module_PCB-B_Mask.gbs, Module_PCB-B_Paste.gbp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]
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2021-07-15 Fixed wrong connection between TX and RETO/RETI
    [Module_PCB-B_Cu.gbl, Module_PCB-B_Mask.gbs, Module_PCB-B_Paste.gbp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]
2021-07-16 Added pull-up for RETI to ensure high-level uart signal when no module follows and the return path is currently disabled
    [Module_PCB-B_Cu.gbl, Module_PCB-B_Mask.gbs, Module_PCB-B_Paste.gbp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]
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2021-07-24 Added Flash reset tested chip erase, block write and continous read
    [flash.c, flash.h]
2021-10-12 Fixed small bug in automatic flash erasing and added some tests
    [flash_sm.c, main.c]
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2021-10-21 fixed flash debug output to not access the flash, when currently reading from the flash in continuous mode
    [flash_sm.c]
2021-10-21 Disabled image flip - there is a bug in it
    [blinkybar.py]
2021-10-22 Fixed ERC errors by adding nc and power indicators
    [Module_PCB.kicad_pcb, Module_PCB.sch]
2021-10-23 Created small adapter board for the main unit to adapt to the two modules
    [main_pcb_adapter.kicad_pcb, main_pcb_adapter.sch, main_pcb_adapter.step]
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2021-10-28 no clue what I changed...
    [main_pcb_adapter.kicad_pcb, main_pcb_adapter.step]
2021-10-28 Added first version of front plate pcb
    [main_pcb_front.kicad_pcb, main_pcb_front.sch, main_pcb_front.step]
2021-10-28 Initial version of user interface board
    [main_pcb_ui.kicad_pcb, main_pcb_ui.sch, main_pcb_ui.step]
2021-10-29 Slightly modification of the front pcb
    [main_pcb_front.kicad_pcb, main_pcb_front.step]
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2021-10-29 First "finieshed" version of the main pcb schematic
    [Main_PCB.sch]
2021-10-29 Minor fixes
    [Module_PCB.kicad_pcb]
2021-10-29 Initial placement of components, replaced Step-Down with LDO due to lack of supplies
    [Main_PCB.kicad_pcb, Main_PCB.sch]
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2021-10-30 Added I2C connection between pi and avr, just in case
    [Main_PCB.kicad_pcb, Main_PCB.sch]
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2021-10-30 Added power button and its protector to the front pcb
    [main_pcb_front.kicad_pcb, main_pcb_front.sch, main_pcb_front.step]
2021-10-30 Added power button to ui, increased size of board, and moved connectors 15 mm up
    [main_pcb_ui.kicad_pcb, main_pcb_ui.sch, main_pcb_ui.step]
2021-10-30 Updated main pcb with power button in ui
    [Main_PCB.kicad_pcb, Main_PCB.sch]
2021-10-30 forgot to add the schematic for main pcb changes a few minutes ago...
    [Main_PCB.sch]
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2021-10-30 Minor fixes to make ERC happy (except one message which I don't understand)
    [Main_PCB.sch]
2021-10-30 Added pin header for ui trigger button for external trigger button
    [Main_PCB.kicad_pcb, Main_PCB.sch]
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2021-10-30 Moved UI to avoid collision with RPi
    [Main_PCB.kicad_pcb, main_pcb_front.kicad_pcb, main_pcb_front.step]
2021-10-30 Corrected position of power button
    [main_pcb_ui.kicad_pcb, main_pcb_ui.step]
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2021-10-31 Fixed ISO number for screws
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2021-11-03 Added MASTER_ON wire also to uC over a large resistor to detect button presses while powered on to turn off, cleaned silk screen
    [main_pcb-B_Cu.gbl, main_pcb-B_Mask.gbs, main_pcb-B_Paste.gbp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]
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2021-11-03 Corrected drill output files
    [main_pcb_adapter.kicad_pcb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]
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2021-11-15 Fixed two MPN
    [main_pcb.csv, main_pcb.sch]
2021-11-15 Added signal names to debug header on silk screen
    [main_pcb-B_Cu.gbl, main_pcb-B_Mask.gbs, main_pcb-B_Paste.gbp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]
2021-11-15 Added comments for connector to modules on silk screen
    [main_pcb-B_Cu.gbl, main_pcb-B_Mask.gbs, main_pcb-B_Paste.gbp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]
2021-11-15 Fixed wrong pinout of p-channel mosfet for power control on main pcb and module pcb
    [main_pcb-B_Cu.gbl, main_pcb-B_Mask.gbs, main_pcb-B_Paste.gbp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]
2021-11-15 Fixed part number of n-channel power mosfet (the selected one was an n-channel)
    [main_pcb.csv, main_pcb.sch]
2021-11-16 Fixed wrong part number
    [main_pcb_ui.csv, main_pcb_ui.sch]
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2021-11-20 Increased front panel PCB holes for buttons to 4mm
    [main_button_protector.f3d, main_button_protector.step, main_button_protector.stl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]
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2021-11-20 Increased the height of the main case a bit
    [main.f3z, main_case.f3d, main_case.step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]
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2021-11-21 New revision of the handle, which is smaller than the previous version
    [main.f3z, main_handle.f3d, main_handle.step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]
2021-11-25 Improved handle design with knob at the top and more space for the fingers
    [main.f3z, main_handle.f3d, main_handle.step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]
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2021-11-27 Modified resistor divider for power measurement, replaced resistor with diode for master button input
    [main_pcb-B_Cu.gbl, main_pcb-B_Mask.gbs, main_pcb-B_Paste.gbp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]
2021-11-27 Moved TRIG wire on a different pin to use timer1 instead of timer0 to have a 16 bit timer, which is also already implemented in the firmware
    [main_pcb-B_Cu.gbl, main_pcb-B_Mask.gbs, main_pcb-B_Paste.gbp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]
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2021-11-28 Fix: send first magic byte
    [main.c]
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2021-11-29 Reset the turn-on-delay to 2000 ms for the modules
    [main.c]
2021-11-30 Added hole for trigger button to main profile
    [main.f3z, main_profile.f3d, main_profile.step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]
2021-12-01 Fixed a couple of issues in the mechanics, noticed after first construction
    [main.f3z, main_case.f3d, main_case.step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]
2021-12-04 Fixed module initialization and mirroring of the image, multiple modules now somewhat working
    [blinkybar.py]
2021-12-04 optimized reset time for LEDs according to datasheet
2021-12-04 Fixed period calculation from speed
    [blinkybar.py]
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2021-12-05 Fixed forwarding of messages
    [main.c]
2021-12-05 Redesigned module finding to work around a hardware design mistake which allows multiple dirvers on the return wire
    [blinkybar.py]
2021-12-06 Optimized module profile for rounted values in drawing
    [module_profile.f3d, module_profile.step, module_profile.stl]
2022-01-16 Corrected wing scre length from 10mm to 12mm
2022-01-17 Fixed module order on the top port
    [blinkybar.py]
2022-01-22 Fixed flash state machine regarding the suspend/resume function
    [flash_sm.c]
2022-01-22 Fixed ADC reading function, which caused the function to hang and give wrong (old) measurements
    [main.c]
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2022-01-29 Disable interrupts when the voltage is too low before powering down
    [main.c]
2022-01-29 Fixed flash page count and implemented the proper wrapping for it
    [flash_sm.c]
2022-01-29 Fixed voltage reading function
    [main.c]
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2022-02-01 Moved the LED control from the Pi to the AVR
    [main_pcb-B_Cu.gbl, main_pcb-B_Mask.gbs, main_pcb-B_Paste.gbp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]
2022-07-14 Hopefully fixed node.js to current versions
